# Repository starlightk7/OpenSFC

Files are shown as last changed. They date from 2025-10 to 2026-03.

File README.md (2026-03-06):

# OpenSFC

## Introduction

This repository contains OSHW Reproduction Parts related to the Super Famicom (SFC) / Super NES (SNES) game console under the umbrella name OpenSFC. While these parts are primarily developed from the Japanese Super Famicom models, you can build a North American SNES as well as long as you use the appropriate front and rear panels. See the documentation for details.

These parts are freely available under the terms of the [CERN-OHL-S](https://github.com/starlightk7/OpenSFC/blob/main/LICENSE) license for you to use, study, modify, or sell. The source files are provided as-is with no warranty or entitlement for support to you or any users that you sell manufactured boards to. See [LICENSE](https://github.com/starlightk7/OpenSFC/blob/main/LICENSE) and [NOTICE](https://github.com/starlightk7/OpenSFC/blob/main/NOTICE) for details. Please carefully read these files to understand your obligations if you choose to distribute this project or modifications of it.

## Sample Build

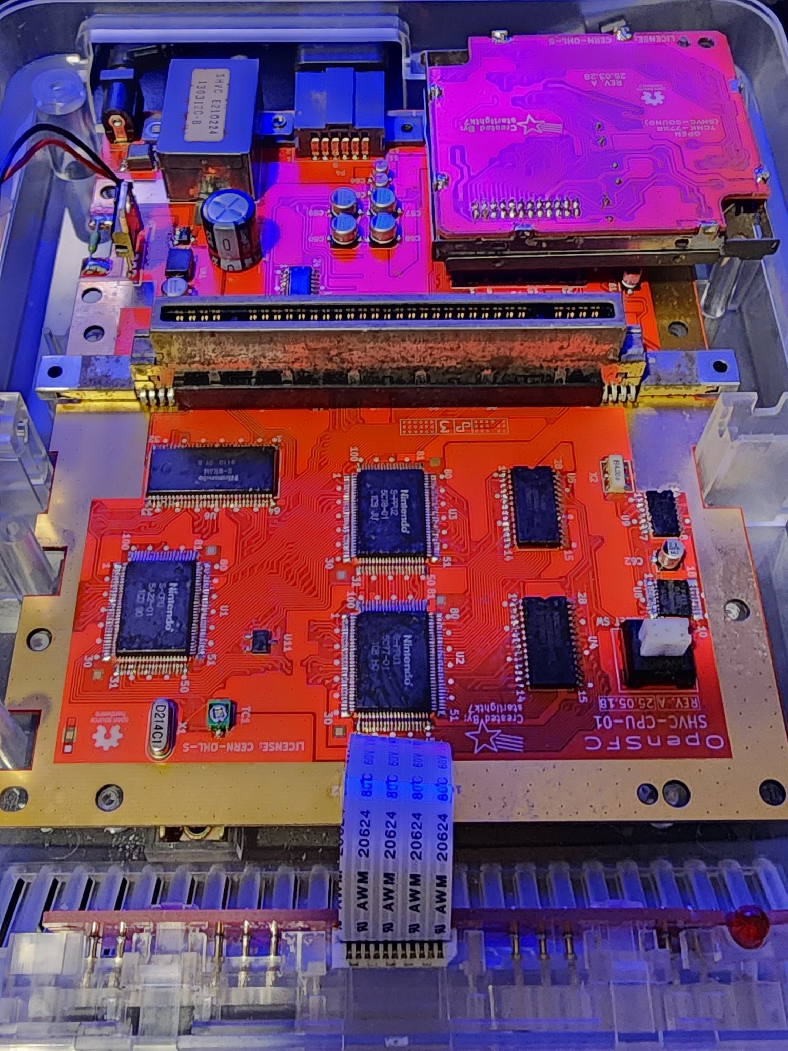
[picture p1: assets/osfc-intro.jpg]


## Usage

Suggested usage for the documents and boards in this repository:

* Studying the hardware and learning about it's function
* Aiding repairs and failure diagnostics through the created [schematics](https://starlightk7.github.io/OpenSFC/#/schematic) and boardviews
* Repairing broken consoles via replacement, reproduction boards and tested replacement [BOMs](https://starlightk7.github.io/OpenSFC/#/bom).
* Building a customized console as a DIY project, for hobby or educational purposes.

## Documentation

Please read the [documentation](https://starlightk7.github.io/OpenSFC/) carefully before using the project.

You can also watch SHVC install videos from [1upRestorations (English)](https://youtu.be/3N_iRRNhPbA), [Assistência Retrô (Portuguese)](https://www.youtube.com/watch?v=s9iTc--j23Y), or [Fenris Wolf Retro (English)](https://youtu.be/6wmiuE3He4w?si=xQSYrtJ7eRGYEiC7).

You can watch a controller install video from [1upRestorations (English)](https://www.youtube.com/watch?v=qigm2QdvjLU)

## Getting a Board

The project officially distributes boards from [Japan (inexpensive international shipping available)](https://ko-fi.com/starlightk7/shop), the [US](https://1uprestorations.com/collections/console-mod-parts/products/opensfc-bundle) and the [UK](https://www.retroupgrades.co.uk/product/opensfc-shvc-bundle). If you just wish to simply obtain a board for yourself, it will often be cheaper than ordering from the fab directly.

***Support is offered to those who purchased a board from a vendor listed below. No support is provided for fabricating these files on your own. If you choose that route, you should understand what you are doing and are responsible for ensuring it is done right. I am not responsible for any defects that may arise from improperly manufacturing these files, or for defects arising from modifications made by you or your PCB fab during manufacturing. If you produce these boards for sale without becoming an authorized distributor, you are responsible for any and all customer support related to the product as well as your compliance with the project's license***. 

If you have any questions about this, feel free to contact with questions. If you are interested in becoming an authorized distributor for your region, and thus gaining support for your users, please contact me via Discord or Twitter.

The ultimate goal of this project is to eventually document and reproduce all models, but it will take quite some time. In the meantime, I made the best overall parts (in my opinion) first. If you believe in the long term goal, consider subscribing on Ko-Fi; for the $1 tier you'll also gain access to weekly Dev Logs that teach how boards like these are made. Labor aside, donor boards to research, prototypes, and parts are all expensive, and those funds will help offset those costs to complete more boards.



Feel free to come chat with us on Discord: 

All boards in this project are 28-35 years old at the time of writing. All relevant patents worldwide have long expired. This project is not affiliated with or endorsed by the big N.

## Commissions

I do not have time to build commissions on a regular basis, however, there are members of the retro community whom offer this service.

| US/Canada | EU |
|---|----|
| [1upRestorations (United States)'](https://1uprestorations.com/collections/pre-modded-consoles/products/opensfc-custom-build) | [Modding Marius](https://moddingmarius.com/super-nintendo/)

## Disclaimer

**WARNING:** Doing a full build is an advanced project. Please carefully read the documentation and required skills and experience before purchasing or ordering a board. Purchasing boards and parts does not guarantee that you can be successful in doing a build. Significant experience in soldering and desoldering, along with a variety of tools are necessary. Your first build will likely not work on its first boot. Patience, analysis, and debugging will likely be necessary to bring the unit online. Order at your own risk. The author provides no guarantee of your success, and also cannot guarantee that any given vendor can fabricate these boards correctly. If you are ordering boards, please consult with your target vendor before ordering if you wish to order a board.

## Parts Index

### Motherboards

| Part Number | Description | Region | Status| Japan | United States | United Kingdom |
|---|---|---|---|---|---|---|
| SHVC-CPU-01 (1990) | The original 2-chip motherboard. This board is the best routed motherboard of all two chip models. Early 1/1/1 Units are extremely reliable. Late 2/1/3 units have a high failure rate. | NTSC-U / NTSC-J | Released | [Ko-Fi (Direct)](https://ko-fi.com/starlightk7/shop), [eBay (Direct)](https://www.ebay.com/itm/136746135648), [Etsy (Direct)](https://starlightretro.etsy.com) | [1upRestorations](https://1uprestorations.com/collections/console-mod-parts/products/opensfc-bundle) | [RetroUpgrades](https://www.retroupgrades.co.uk/product/opensfc-shvc-bundle) |
| SNS-CPU-GPM-01 (1991) | Contains the often failing CPU 2A. | NTSC-U / NTSC-J | In Progress | N/A | N/A | N/A |

### Sound Module

| Part Number | Description | Region | Status| Japan | United States | United Kingdom |
|---|---|---|---|---|---|---|
| TCMK-77XR SHVC-SOUND | The early type, missing resistors on the 2904. Repro for historical purposes only. | NTSC-U / NTSC-J | Planned | N/A | N/A | N/A |
| TCMK-77XR SHVC-SOUND F | This is the late model sound module which fixed missing resistors on the 2904. | NTSC-U / NTSC-J | Released | [Ko-Fi (Direct)](https://ko-fi.com/starlightk7/shop), [eBay (Direct)](https://www.ebay.com/itm/136746135648), [Etsy (Direct)](https://starlightretro.etsy.com) | [1upRestorations](https://1uprestorations.com/collections/console-mod-parts/products/opensfc-bundle) | [RetroUpgrades](https://www.retroupgrades.co.uk/product/opensfc-shvc-bundle) |

### Front Panel Board

| Part Number | Description | Region | Status| Japan | United States | United Kingdom |
|---|---|---|---|---|---|---|
| TCMK-81X CCK-N10 | Found in SHVC and GPM Super Famicoms | NTSC-J | Released | [Ko-Fi (Direct)](https://ko-fi.com/starlightk7/shop), [eBay (Direct)](https://www.ebay.com/itm/136746135648), [Etsy (Direct)](https://starlightretro.etsy.com)| [1upRestorations](https://1uprestorations.com/collections/console-mod-parts/products/opensfc-bundle) | [RetroUpgrades](https://www.retroupgrades.co.uk/product/opensfc-shvc-bundle) |
| TCMK-81X CCK-N20 | Found in SHVC and GPM North American SNESes | NTSC-U | Released | [Ko-Fi (Direct)](https://ko-fi.com/starlightk7/shop), [eBay(Direct)](https://www.ebay.com/itm/136746135648), [Etsy (Direct)](https://starlightretro.etsy.com) | [1upRestorations](https://1uprestorations.com/collections/console-mod-parts/products/opensfc-bundle) | [RetroUpgrades](https://www.retroupgrades.co.uk/product/opensfc-shvc-bundle) |

### Controllers

| Part Number | Description | Region | Status| Japan | United States | United Kingdom |
|---|---|---|---|---|---|---|
| 56V313A (1990.6) | Found in 1/1/1 SHVC controllers. 2x shift register model | NTSC-J / NTSC-U | Released | [Ko-Fi (Direct)](https://ko-fi.com/starlightk7/shop), [eBay(Direct)](https://www.ebay.com/itm/137100897247) | [1upRestorations](https://1uprestorations.com/products/opensfc-controllers) | [RetroUpgrades](https://www.retroupgrades.co.uk/) (Coming Soon) |
| 56V313B (1991) | Found in 2/1/3 SHVC controllers. 1x Obsolete Shift Register, no PAL support | NTSC-J / NTSC-U | Planned | N/A | N/A | N/A |
| 56V313D (1992+)  | Found in controllers for GPM and beyond. 1x Obsolete Shift Register | Universal | Released | [Ko-Fi (Direct)](https://ko-fi.com/starlightk7/shop), [eBay(Direct)](https://www.ebay.com/itm/137100898087) | [1upRestorations](https://1uprestorations.com/products/opensfc-controllers) | [RetroUpgrades](https://www.retroupgrades.co.uk/) (Coming Soon) |
| 56V313A | L/R Trigger Board | Universal | Released | [Ko-Fi (Direct)](https://ko-fi.com/starlightk7/shop) | [1upRestorations](https://1uprestorations.com/products/opensfc-controllers) | [RetroUpgrades](https://www.retroupgrades.co.uk/) (Coming Soon) |

### Cartridges

There are none currently in progress, but they are planned for future.

### Accessories

There are none currently in progress, but they planned for future.

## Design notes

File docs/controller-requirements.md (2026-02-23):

# Requirements

## Skills

The following skills are required to successfully complete this project

* Soldering Skills
  * Must be able to solder through hole resistors
  * Must be able to solder a SOIC/SOP style IC

* Desoldering skills
  * Must be able to desolder a SOIC/SOP style IC

* Multimeter
  * Must understand basic use of a multimeter and how to test continuity and voltage

## Tools

The following tools are required to successfully complete this project

* Minimum
  * Soldering iron
  * Solder
    * Leaded 63/37
    * Low Melt Solder (strongly recommended)
  * Flux
  * Desoldering wick
  * 3-11 220ohm 1/4w size through hole resistors.
  * 5mm hole punch
  * 0.1mm thickness sticker paper
  * 99% Isopropyl Alcohol
  * Q-Tips/Toothbrush for Cleaning
  * Multi-meter

* Recommended
  * Temperature controlled soldering iron
    * J-Tip for QFP Soldering / Desoldering
    * Spatula Tip (optional, but makes pre-tinning much easier)
  * Solder
    * Kester 63/37 w/ Rosin Core (any reputable brand is fine)
    * ChipQuik Low Melt Solder
  * Goot Wick Desoldering Braid
    * This stuff is the best braid I've ever used. Great for cleaning the chip legs.
  * Tacky Flux such as ChipQuik SMD291 (any brand is fine)
  * Kapton Tape
    * Protect the button contacts. The board is ruined if you get solder on them.
  * Anti-static wristband
    * Failure to use one may cause ESD damage to parts. This is not always instant; a zap may cause damage that may make it fail at a delay.
  * Safety glasses
    * Please wear them. The time you don't have them can be the time you really needed them
  * Fume extractor
    * Prolonged fumes are bad for you health. If you do not have an extractor at least work near and open window and blow a fan toward it if you can.

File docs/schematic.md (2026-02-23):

# Schematics

## Notes on Schematics
This page contains PDFs of schematics I created for OpenSFC.

Please note that my schematics are not traditional engineering schematics. I am not an engineer, just a hobbyist. I have seen many other hobbyists struggle to decode complex schematics and map them back to their boards, often needing someone else to interpret for them. 

I envision the primary users of my boards being hobbyists with a little knowledge of a soldering iron who want to repair their unit or build a fun project, not professional engineers. As such I have chosen to draw my schematics more as "Schematic Art". They are laid out like a visual depiction of the actual board. 

This will likely feel messy and inefficient to a professional engineer, but for an average person they will clearly be able to correlate what they are looking at to the board they are working on and see the color coded flow of data by function when debugging. 

This approach will have people who both like and dislike it and that's okay. The beauty of Open Source is anyone is free to remix it to suit their needs. If you prefer a more traditional schematic, you can also reference the existing  [J. Donaldson schematic](https://wiki.superfamicom.org/uploads/snes_schematic_color.pdf). Please note that despite having a section for the SHVC-SOUND Pinout the Donaldson Schematic is a GPM Schematic. There are numerous differences with SHVC and other models, so you cannot count on it for passive values when doing an OpenSFC SHVC build. You can, however, see how ICs are generally connected with it.

## PDF Diagrams

* Motherboard
  * [SHVC-CPU-01 Front](https://starlightk7.github.io/OpenSFC/assets/SHVC-CPU-01-Front.pdf)
  * [SHVC-CPU-01 Back](https://starlightk7.github.io/OpenSFC/assets/SHVC-CPU-01-Back.pdf)
* Sound Module
  * [TCMK-77XR SHVC-SOUND F](https://starlightk7.github.io/OpenSFC/assets/TCMK-77XR-F.pdf)
* Front Panel Controller Board
  * [TCMK-81X CCK-N10 SFC Style (SHVC/GPM)](https://starlightk7.github.io/OpenSFC/assets/TCMK-81X_CCK-N10.pdf)
  * [TCMK-81X CCK-N20 SNES Style (SHVC/GPM)](https://starlightk7.github.io/OpenSFC/assets/TCMK-81X_CCK-N20.pdf)
* Controllers
  * [56V313A (1990 Model)](https://starlightk7.github.io/OpenSFC/assets/53V313A.pdf)
  * [56V313D (1992+ Model)](https://starlightk7.github.io/OpenSFC/assets/53V313D.pdf)
  * [56V314A (Shoulder Button)](https://starlightk7.github.io/OpenSFC/assets/53V314A.pdf)

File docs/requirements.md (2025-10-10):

# Requirements

## Skills

The following skills are required to successfully complete this project

* Soldering Skills
  * Must be able to solder through hole components
  * Must be able to solder 0805 size SMD passives
  * Must be able to solder fine pitch QFP chips

* Desoldering skills
  * Must be able to desolder through hole components
  * Must be able to desolder QFP chips without damaging them

* Multimeter
  * Must understand basic use of a multimeter and how to test continuity and voltage

## Tools

The following tools are required to successfully complete this project

* Minimum
  * Soldering iron
  * Solder
    * Leaded 63/37
    * Low Melt Solder (strongly recommended)
  * Flux
  * Desoldering wick
  * Desoldering Gun or Pump (Strongly Recommneded)
  * 99% Isopropyl Alcohol
  * Q-Tips/Toothbrush for Cleaning
  * Multi-meter

* Recommended
  * SNES Burn In Cart, or ROM on a Flash Cart
    * Access to this highly recommended. If you don't know if the chips in your system work properly to begin with you will have a hard time debugging if it is your first build.
    * If using SD2SNES, turn off all in-game hooks and save states or it can cause errors on the tests, particularly with the timing tests.
  * Temperature controlled soldering iron
    * J-Tip for QFP Soldering / Desoldering
    * Spatula Tip (optional, but makes pre-tinning much easier)
  * Solder
    * Kester 63/37 w/ Rosin Core (any reputable brand is fine)
    * ChipQuik Low Melt Solder
  * Goot Wick Desoldering Braid
    * This stuff is the best braid I've ever used. Great for cleaning the chip legs.
  * Tacky Flux such as ChipQuik SMD291 (any brand is fine)
  * FR-301 Desoldering Gun or Equivalent
    * 1.6mm Tip for Controller Ports
    * 0.8mm Tip for Connectors
  * Kapton Tape
    * Protect the beautiful ENIG plane
  * Anti-static wristband
    * Failure to use one may cause ESD damage to parts. This is not always instant; a zap may cause damage that may make it fail at a delay.
  * Safety glasses
    * Please wear them. The time you don't have them can be the time you really needed them
  * Fume extractor
    * Prolonged fumes are bad for you health. If you do not have an extractor at least work near and open window and blow a fan toward it if you can.

* Optional
  * Some people may want Hot Air Station or Hot Plate, but these are not strictly necessary. If you don't have one you do need a J-Tip and ChipQuik Low melt. I recommend low melt solder regardless and keeping your station temperature lower to avoid damaging the chips.

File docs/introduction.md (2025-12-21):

# Introduction

Welcome to OpenSFC!

This is an Open Source Hardware (OSHW) project aimed at creating 1:1 reproduction part for SFC / SNES consoles for use in repair and customization. In addition, parts will be documented, schematics drawn, and replacements for obsolete parts identified where possible.

# Sample OpenSFC Build
image|300x400

# Install Videos

These videos from the community demonstrate the installation process:
* [1up Restorations OpenSFC Installation Video (English)](https://youtu.be/3N_iRRNhPbA)
* [Assistência Retrô OpenSFC Install Video (Portuguese)](https://www.youtube.com/watch?v=s9iTc--j23Y)
* [Fenris Wolf Retro OpenSFC Installation Video (English)](https://youtu.be/6wmiuE3He4w?si=xQSYrtJ7eRGYEiC7)

# Why Would I Want This?

There are many reasons why you might want an OpenSFC part

* Repairing Damage to Original Boards
  * Boards can be damaged by a variety of incidents
    * Leaked Capacitors
    * Liquid Spills
    * Flooded basements/warehouses
    * Humidty damage from improper storage
    * Failed mod attempts
  * These parts can serve as replacement parts to repair the unit.
* Learning
  * You may want to learn about how our beloved console works
  * The ability to build one by hand is an excellent way to gain some insight into how the console works
* Customization
  * Some people find joy in customizing a beat-up unit while restoring it, and OSHW parts are great for that. 
  * Please be responsible and choose a rustic unit for your restoration so that we don't needlessly deplete the supply of original units in good condition
* Integrating fixes/mods
  * The reference board is a 1:1 reproduction, but you may want to customize it.
  * You may want to remix a custom board that integrates mods or fixes of your choice into the board.
  * Anyone can create a derivative under the terms of the [CERN-OHL-S](https://ohwr.org/cern_ohl_s_v2.txt) license.

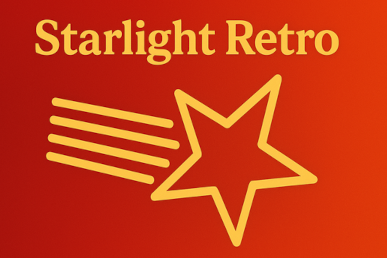
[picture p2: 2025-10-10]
assets/header.png

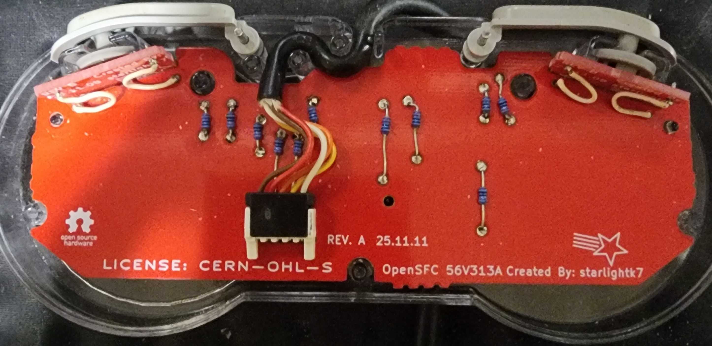
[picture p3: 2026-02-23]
assets/56V313A_Back.jpg

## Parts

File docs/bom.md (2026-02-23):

# Bill of Materials (BOM)

## Parts List

A list of compatible parts are 
The [following spreadsheet](https://docs.google.com/spreadsheets/d/1zoEOy6N3Ll8hXqOk3DKFTWjwM4TRxby1sjQ6yHRMT5c) contains a description of required donor parts for the project as well as a mouser-based BOM if you'd like to use as many new parts as possible'. Each board has its own sheet.

Quick Links:

## Interactive Guides for Assembly Assistance

These files visually show you where a given part number is located on the board. It is harder to keep these resources up to date with in-stock parts, so the actual part list is maintained in the spreadsheet above.

* [SHVC-CPU-01](https://starlightk7.github.io/OpenSFC/ibom/ibom-shvc.html)
* [SHVC-SOUND F](https://starlightk7.github.io/OpenSFC/ibom/ibom-sound.html)
* [SFC Front Panel](https://starlightk7.github.io/OpenSFC/ibom/ibom-n10.html)
* [SNES Front Panel](https://starlightk7.github.io/OpenSFC/ibom/ibom-n20.html)

## Donor Identification

### Japanese Units

These are general guidelines for identifying Japanese units. Note that there may be exceptions if someone has shell swapped units.
 * SHVC
   * 4 Rubber Feet on Bottom. This is your primary target.
 * GPM
   * 2 Rubber Feet, 2 Plastic on Bottom.
   * Serial Begins with S0/S1/S2 (no "SM")
 * RGB/APU/1-CHIP
   * 2 Rubber Feet, 2 Plastic on Bottom.
   * Serial Begins "SM"

### Compatibility Notes

#### SHVC-CPU-01 Repro
As of the time of writing, the only out of box fully compatible unit with the current SHVC-CPU-01 repro is the SHVC, because of the need for the proprietary SHVC-SOUND connectors. You can harvest chips from any broken unit though. It does not matter which revision of the chips you use. Do note though that CPU 2A is substantially more likely to fail under normal circumstances than CPU 1 or 2B. CPU 2A is found in late SHVCs and early GPMs.

A GPM unit can be converted if 2.0mm pitch pin headers of the right length are used for the SHVC-SOUND, and new op-amps are used. I am working on identifying a set that will allow it to sit cleanly on the screwpost. No support is provided for this currently until a fully compatible set of parts is identified.

Converting a RGB unit would additionally require the older BA6592F / S-ENC encoder if is RGB-01, and also the older NEC µPD6376 if RGB-02. These parts are obsolete, though can sometimes be found on AliExpress. The supply is spotty though and some sellers are scammers. Not recommended at this time until reliable part sources are identified.

Converting an APU unit is not courrently possible. A custom SHVC-SOUND that is compatible with the S-APU unit would be needed. I plan on making one in the future.

If you wish to build a North American SNES, please note that neither aftermarket shell option includes the necessary springs for the North American Shell. So you cannot have a properly functioning case with a Japanese donor. I am currently working on identifying suitable replacement springs to solve this.

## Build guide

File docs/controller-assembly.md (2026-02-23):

# Assembly

## Official Install Video

Coming Soon

## General Guidelines

**Please carefully follow the following steps**

Identify which controller model your donor is before purchasing. You will need the matching board as your donor.

WARNING: if you are sloppy with your work consider covering the button contacts with kapton tape. If you get any solder on the button contacts the board is permanently damaged and when it oxidizes the pads will stop working correctly. As such, if you happen to be producing your own boards, DO NOT USE HASL BOARDS for controllers. They will degrade quickly especially in humid climates.

### 1990 Model:

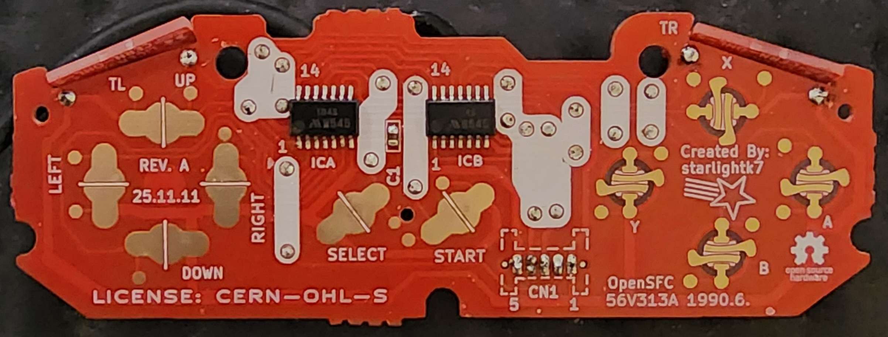
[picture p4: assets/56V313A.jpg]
image|601x228


* Features 2 8-bit shift registers with a non-standard pinout
* Various carbon printed resistors are used (white silk on the ENIG repro)
* Desolder and transfer the 2 shift registers. Chipquik will make it super easy.
* Transfer the decoupling capacitor C1
* Install 220ohm 1/4W size through hole resistors to replace the carbon, as ENIG has no resistance
* For this model, I recommend installing them on the back like so to avoid conflicts with pegs. Be conscious of clearance.
* Install the resistors *before* the cable connector to make your life easier on the ones near it

image|601x292

### 1992 Model:

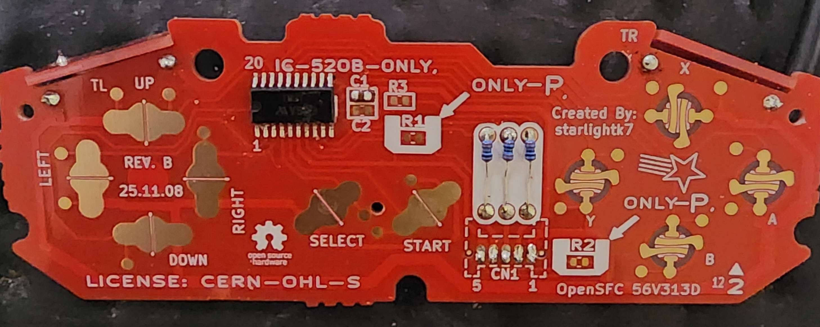
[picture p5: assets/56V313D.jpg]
image|601x239


* Features a single 16-bit shift registers with a non-standard pinout
* 3 carbon printed resistors are used as part of input protection
* Desolder and transfer the shift registers. Chipquik will make it super easy.
* Transfer the decoupling capacitor C1. 
* If PAL donor board, transfer the Only-P resistors
* Install 220ohm 1/4W size through hole resistors to replace the carbon, as ENIG has no resistance
* For this model, I recommend installing them on the front like so to avoid conflicts with pegs. Be conscious of clearance, they must be pulled up top to not hit.
* You may also install these on the back like the 1990 model, but in that case due it before installing the cable connector.

### Tuning Sensitivity

Making custom controllers is a bit of an art due to micro-tolerance issues. All parts being produced today tend to have ~0.1~0.3mm tolerance ranges; this applies to everything, PCBs, Silicone Pads, Dpads/Buttons, Shells, etc.

When building a custom controller it is possible that the combination of parts you use will have microtolerance issues, leading to decreased sensitivity on inputs. This also effects the stock PCB, which is why 3rd party Silicone pads are notorious for stiff diagonals. As my boards are 1:1 copies of stock, they may encounter the same problems.

Luckily, there is a cheap and easy way to tune these issues to your liking.

Before tuning, turn on and test your controller. I recommend doing something like sliding in Super Mario and also diagonal movements in Zelda. It is highly possible, especially with 3rd party silicone pads or cases. Basically, 3rd party pads often are actually slightly big or small compared to the original ones. When you press, that makes them bend differently. I took some mitigations against this by widening the stock contacts a little and minimizing the distance between size, but it occasionally happens on a diagonal.

I recommend taking a 5mm hole punch onto 0.1mm sticker paper. Then start to augment the d-pad like so:

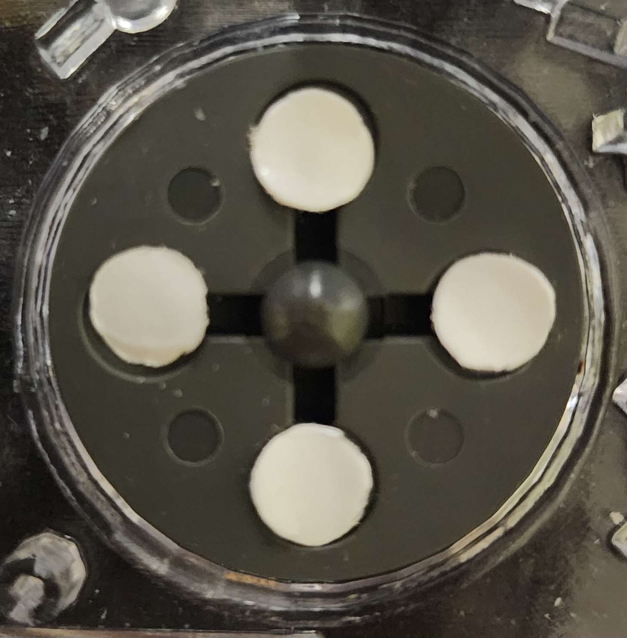
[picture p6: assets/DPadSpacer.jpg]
image|364x370


Do it in 0.1mm increments until it feels right to you. Basically what happens here is, each layer of sticker will reduce how hard you must press on the pad to make contact. Usually no more than 0.3mm is needed

If you are using 3D printed parts, tuning is often not necessary since they are naturally thicker. But if you have any difficulty, use this process.

If you want to tune the buttons, put the sticker on the underside of the buttons.

If you want to tune the L/R triggers, you can do the underside of the trigger or the underside of the trigger board.

One tuned, the controller should feel very comfortable. Feel free to reach out if you need help

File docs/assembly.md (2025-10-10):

# Assembly

## Official Install Video

[1upRestorations](https://1uprestorations.com) has graciously provided an [official install video](https://youtu.be/3N_iRRNhPbA).

## General Guidelines

**Please carefully follow the following steps**

* Discharge the donor unit with power on while unplugged before starting. There is no bleeder on the filter cap, so it retains charge and can cause damage to the sytem or blow the fuse if you do not discharge it before working on the unit.

* Build the sound and controller modules first and test them independently. 
  * If your donor is working, you can test your sound module in it before removing the chips from the motherboard. 
  * The system will not boot if the audio module doesnt work, so being able to verify that piece independently is very nice. 
  * Hakko FR-301 with 1.6mm tip makes quick work of swapping the controller input board.

* Before doing anything on the mainboard, I recommend protecting the ENIG ground plane on the new board with kapton tape. 
  * **WARNING: If you contaminate the ENIG gold with solder it is PERMANENT DAMAGE. There is no getting it out without the ENIG being replated and the solder will ruin the beautiful gold look** 
  * Additionally, there are many small enig test pads all over the back of the board. 
     * You will need to decide how OCD you will be about contamination. 
     * When I assembled my first board by hand I moved a small piece of kapton around as I went to protect these. As such, my board retained a very pretty gold emphasis.
     * You must control paste very well to not contaminate the pads if you are using an oven/hotplate/hotair assembly. If you want it to be perfect I recommend hand soldering with kapton shields.

* There are several options for assembly
  * You can solder each part by hand. 
  * You can pre-tin the pads and transfer with hot tweezers if you have them. 
    * Transplants can also be done extremely fast that way.
  * You can dispense solder paste, place the parts, and bake them in a reflow oven or on a hot-plate
  * Clean the board good with IPA before testing. Some types of flux are conductive and can cause shorts.
    * If you have an ultrasonic cleaner, I recommend using it, but do so *before* installing the Crystal Oscillators / Ceramic Resonators as they can be sensitive to ultrasonic cleaning.
    * If you do not have one, a great budget strategy is to take a gallon freezer bag, pour IPA into it, and put the board inside. You can gently shake it, as well as reach in a tooth brush and scrub with more volume, and without the IPA evaporating quickly.
* I recommend doing the back side first or the board wont sit level while youre doing it and that sucks

* Before soldering any chips **pre-tin all of the pads or you'll have a difficult time especially if you are a novice**. 
  * The easiest way is if you have a spatula tip, as that can quickly pre-tin them evenly with little risk of burning a pad. I do it around 300c with a little flux.
  * If you do not have a spatula tip, wick away excess solder so that when you place the chip it lays flat, otherwise you'll have trouble with alignment

* After soldering chips, poke test each leg with tweezers for any loose. 
  * Looks can be highly deceiving and so can the multimeter as the pressure from the tip will often provide enough pressure to conduct even if its loose.
  * The most common cause of issues is a loose QFP leg or cold joint on one.

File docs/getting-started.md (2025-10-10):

# Getting Started

Welcome! This is a placeholder page you can edit or replace.

- Navigation lives in `/docs` and is configured in `DOC_PAGES` in `script.js`.
- Images placed under `/assets` can be referenced as `../assets/...`.

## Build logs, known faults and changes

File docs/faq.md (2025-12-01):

# FAQ

**Q:** Will you be doing boards for other models?

**A:** I intend to eventually reproduce all NTSC variants, however this will take quite some time. I can make no guarantees on the timing of release. In the meantime, the best routed 2-CHIP SFC board is the SHVC which is already reproduced. These have the least amount of quality problems. For PAL consoles, please google the nonSNES project. I am currently in need of SNS-1CHIP-01 and SNS-1CHIP-03. I also need a US variant of an RGB/APU/1-CHIP in order to look at the late model controller input board. If you wish to sell or donate one of these units for R&D, please contact me.

**Q:** Can I build a SNES instead of an SFC?

**A:** Yes, as long as you buy the correct front panel and get a SNES rear power panel, either from a donor or one of the aftermarket parts. However, if your donor is a Super Famicom, none of the aftermarket kits current include the springs required for the shell, and the ones from the Super Famicom are NOT compatible. I working on identifying aftermarket replacements, but in the meantime, if you want to build a SNES, your donor should also be one to use these springs.

**Q:** Why is red significantly more expensive?

**A:** The fabs charge a substantial premium for red, and this premium is amplified x3 because of there being 3 boards. Unfortunately even with a volume purchase there's no way to avoid the price needing to be higher 😔

**Q:** Can I commission you for a pre-built?

**A:** In general I will not have time to do this on an ongoing basis, however, I may irregularly list pre-builts on the Ko-Fi store of units that were used for build validation. Once these are gone, they're generally gone unless there is development need to build another. [1upRestorations](https://1uprestorations.com) will provide a [custom build service](https://1uprestorations.com/collections/pre-modded-consoles/products/opensfc-custom-build) for customers in the US/Canada if you wish to commission a pre-built. [Modding Marius](https://moddingmarius.com/super-nintendo/) will take commissions for a pre-built out of France for EU residents.

**Q:** Can I use **&lt;insert mod x&gt;**?

**A:** Any mod that is compatible with the original SHVC should be compatible with OpenSFC. However, if you have modified the BOM, or done other community recommended fixes, keep in mind that deviation from the stock part configuration may adversely effect mods, especially in the case of edge mods.

**Q:** Why didn't you integrate **&lt;insert common community bodge fix&gt;**?

**A:** I am first and foremost most interested in historical preservation, which means preserving the stock design. While I am open to making revised versions in the future, not all of these fixes and mods are compatible with each other. I want to study the issues in detail before investing in any enhanced boards. I cannot promise I will make any such boards in the future, but there is nothing stopping someone else from doing so either. You may also freely apply these fixes yourself in the same way as stock, or remix the board to include them and order a copy for yourself.

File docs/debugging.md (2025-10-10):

# Debugging

This page will cover commons checks and procedures.

## The Basics

You will need to use a multimeter for diagnostics. There are two main types of tests you will need to perform: continuity and and voltage.

### Continuity Tests
* This will test that there is an electrical connection between the two points you touch with your probes.
   * Turn multimeter to continuity mode.
   * **Before testing, unplug the unit and turn the power button on to discharge the filter cap**. You will see the power LED briefly flicker. Never test continuity with the unit plugged in as you can damage components
   * Touch the probe between the two points. You should get 0 and a beep if successful. If you do not hear a beep, the number on the screen is the resistance between the points.

## Controller Module
* Before power on, ensure the filter cap is discharged and
  * Check for short between VCC/GND
    * Power off, filter cap discharged. Ribbon connected to the board.
    * Turn to Continuity Mode
    * Touch the red probe to the VCC pin on the connector. 
    * Touch the black probe to GND. Use the GND pin on the connector
    * You should not hear a beep and should see several hundred ohms of resistance. If you hear a beep DO NOT POWER ON. Fix short first.

## Sound Module

* Before power on.. 
  * Check for short between VCC/GND
    * Power off, filter cap discharged or SHVC SOUND disconnected from motherboard
    * Turn to Continuity Mode
    * Touch the red probe to the VCC pin on the connector. 
    * Touch the black probe to GND. The shield is connected to ground, or you can use the GND pin.
    * You should not hear a beep and should see several hundred ohms of resistance. If you hear a beep DO NOT POWER ON. Fix short first.
  * Check for short between AVCC/GND
    * Power off, filter cap discharged or SHVC SOUND disconnected from motherboard
    * Turn to Continuity Mode
    * Touch the red probe to the AVCC pin on the connector.
    * Touch the black probe to GND. The shield is connected to ground, or you can use the GND pin.
    * You should not hear a beep and should see several hundred ohms of resistance. If you hear a beep DO NOT POWER ON. Fix short first.
* If the unit doesnt work, proceed in this order:
  * Verify 5V power rail
    * Multimeter in DC Voltage mode.
    * Use the VCC pin on the connector. Look for stable 5V (voltage mode, power on).
    * The shield is connected to ground, or you can use the GND pin.
    * Look for stable 9V (DC voltage mode, power on).
  * Verify 9V power rail
    * Multimeter in DC Voltage mode.
    * Touch the red probe to the the AVCC pin on the connector.
    * Touch the black probe to GND. The shield is connected to ground, or you can use the GND pin on the connector.
    * Look for stable 9V (DC voltage mode, power on).
  * Verify clock
    * The ceramic resonator is the clock, but you will destabilize it if you measure it directly. Instead check for activity on Pin 16 (CLK, lower left) on the uPD6376. If it isn't dead, you've got clock.
  * Verify SMP/DSP pins
    * Poke test each of the legs with the unit is off. Make sure not on floating
    * Use a microscope, reading glasses or your cell phone camera to check for bridges.
  * At this point the unit should be booting if attached to a working motherboard.

* If boots but no audio
  * Verify soldering in the op-amp/encoder section of the board.

* If audio sounds too quiet/loud: 
  * Check for mistakes in capacitor values in the op-amp circuit

# Motherboard

## Initial Bring Up

* Before power on:
  * Check for shorts on 5V/GND
    * Unplug unit
    * Discharge filter cap
    * Red probe right leg of 7805
    * Black probe middle.
    * No beep expected.
  * Check for shorts between 9V/GND
    * Unplug unit
    * Discharge filter cap
    * Red probe left leg of 7805
    * Black probe middle.
    * No beep expected.

* If the unit doesnt work, proceed in this order:
  * Verify power rails
    * Power On
    * DC Voltage Mode
    * 5V
      * Red Probe: Right leg of 7805
      * Black Probe: Use the exposed GND rim to prevent accidental short from touching your probes.
    * 9V
      * Red Probe: Left leg of 7805
      * Black Probe: Use the exposed GND rim to prevent accidental short from touching your probes.
  * Verify clocks
    * Voltage probe for life on CIC CLK (see schmatic)
    * Voltage probe for life on SYSCLK (see schmatic)
  * Verify Sound module
    * See above section for tests
  * Verify CIC

**At this point should be booting in some form**

## Further Troubleshooting
* No Power:
  * Check fuse. Not resettable so if blown needs to be replaced. Do not use slow blow fuses. 
    * Unplug unit
    * Discharge filter cap
    * Continuity test across the fuse
    * Multimeter should beep
  * If installing a resettable fuse, make sure its fast blow at least as fast as the pico fuse or the hardware may be damaged. 
  * A slow blow fuse will likely damage things before tripping.

* Power Brownout (power is significantly less than 5v at the 7805 output)
  * Make sure you used the right diode arrays in the right spot. If they are swapped you will brown out.

* Black Screen
  * If you have CPU 2A, pray it wasn't dead if you didn't verify it before-hand with the SNES burn in test.
  * Verify CPU<->S-WRAM pins
    * Poke test all legs

* Scrambled graphics:
  * Verify PPU<->VRAM pins
    * Poke test all legs

* Bad Color:
  * Verify video output lines (RGB, etc) lines
    * Use the color codes lines on the schematic.
    * First inspect for soldeirng issues
    * Probe for life at each point.
    * In particular, check the transistors.

* No Input
  * Verify connector/ribbon orientations

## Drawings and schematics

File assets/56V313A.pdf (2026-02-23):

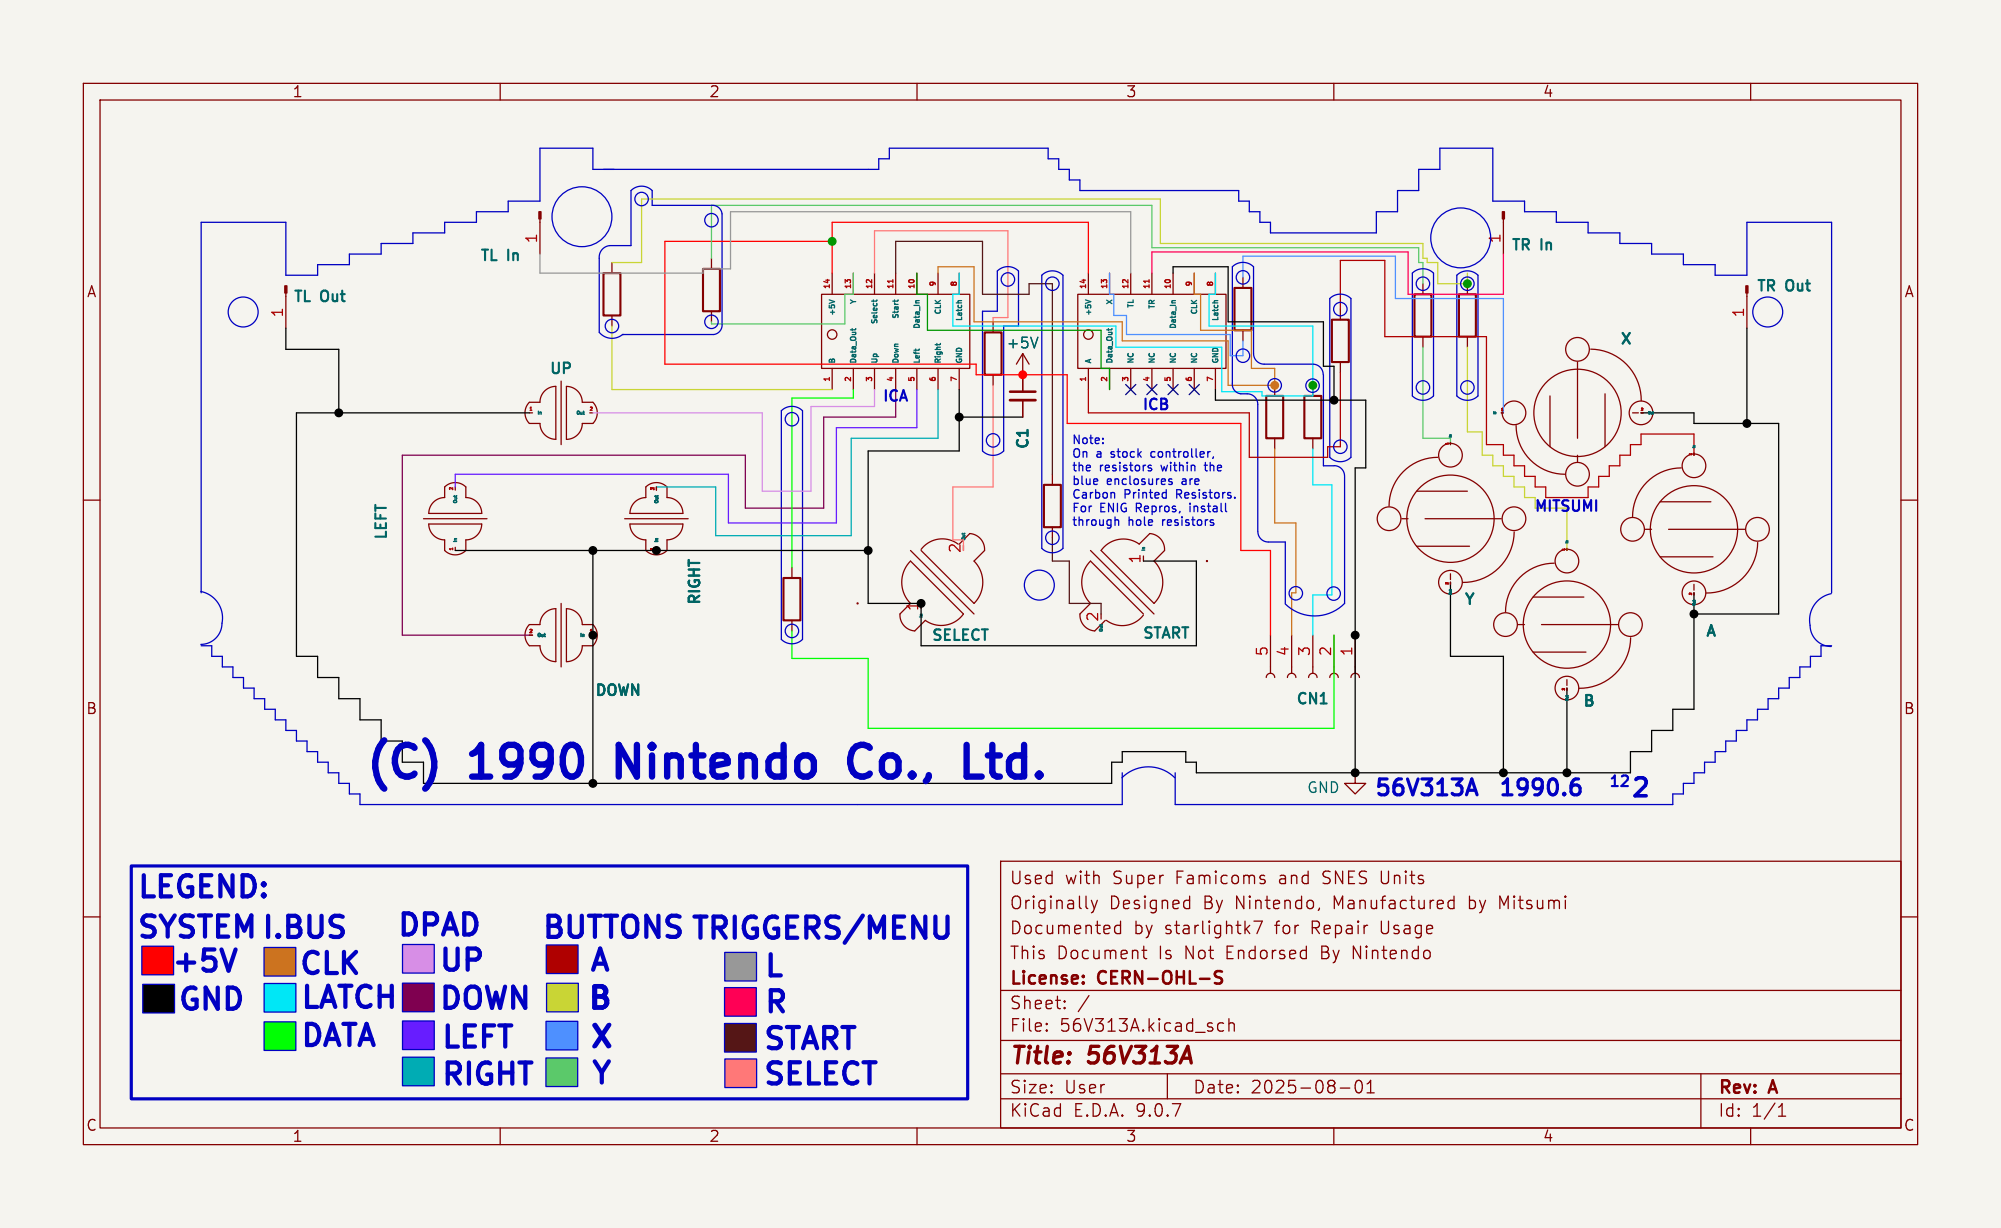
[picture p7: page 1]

Note: On a stock controller,

1 CN1 Out 2 In 1 SELECT In

File: 56V313A.kicad_sch Sheet: / License: CERN-OHL-S

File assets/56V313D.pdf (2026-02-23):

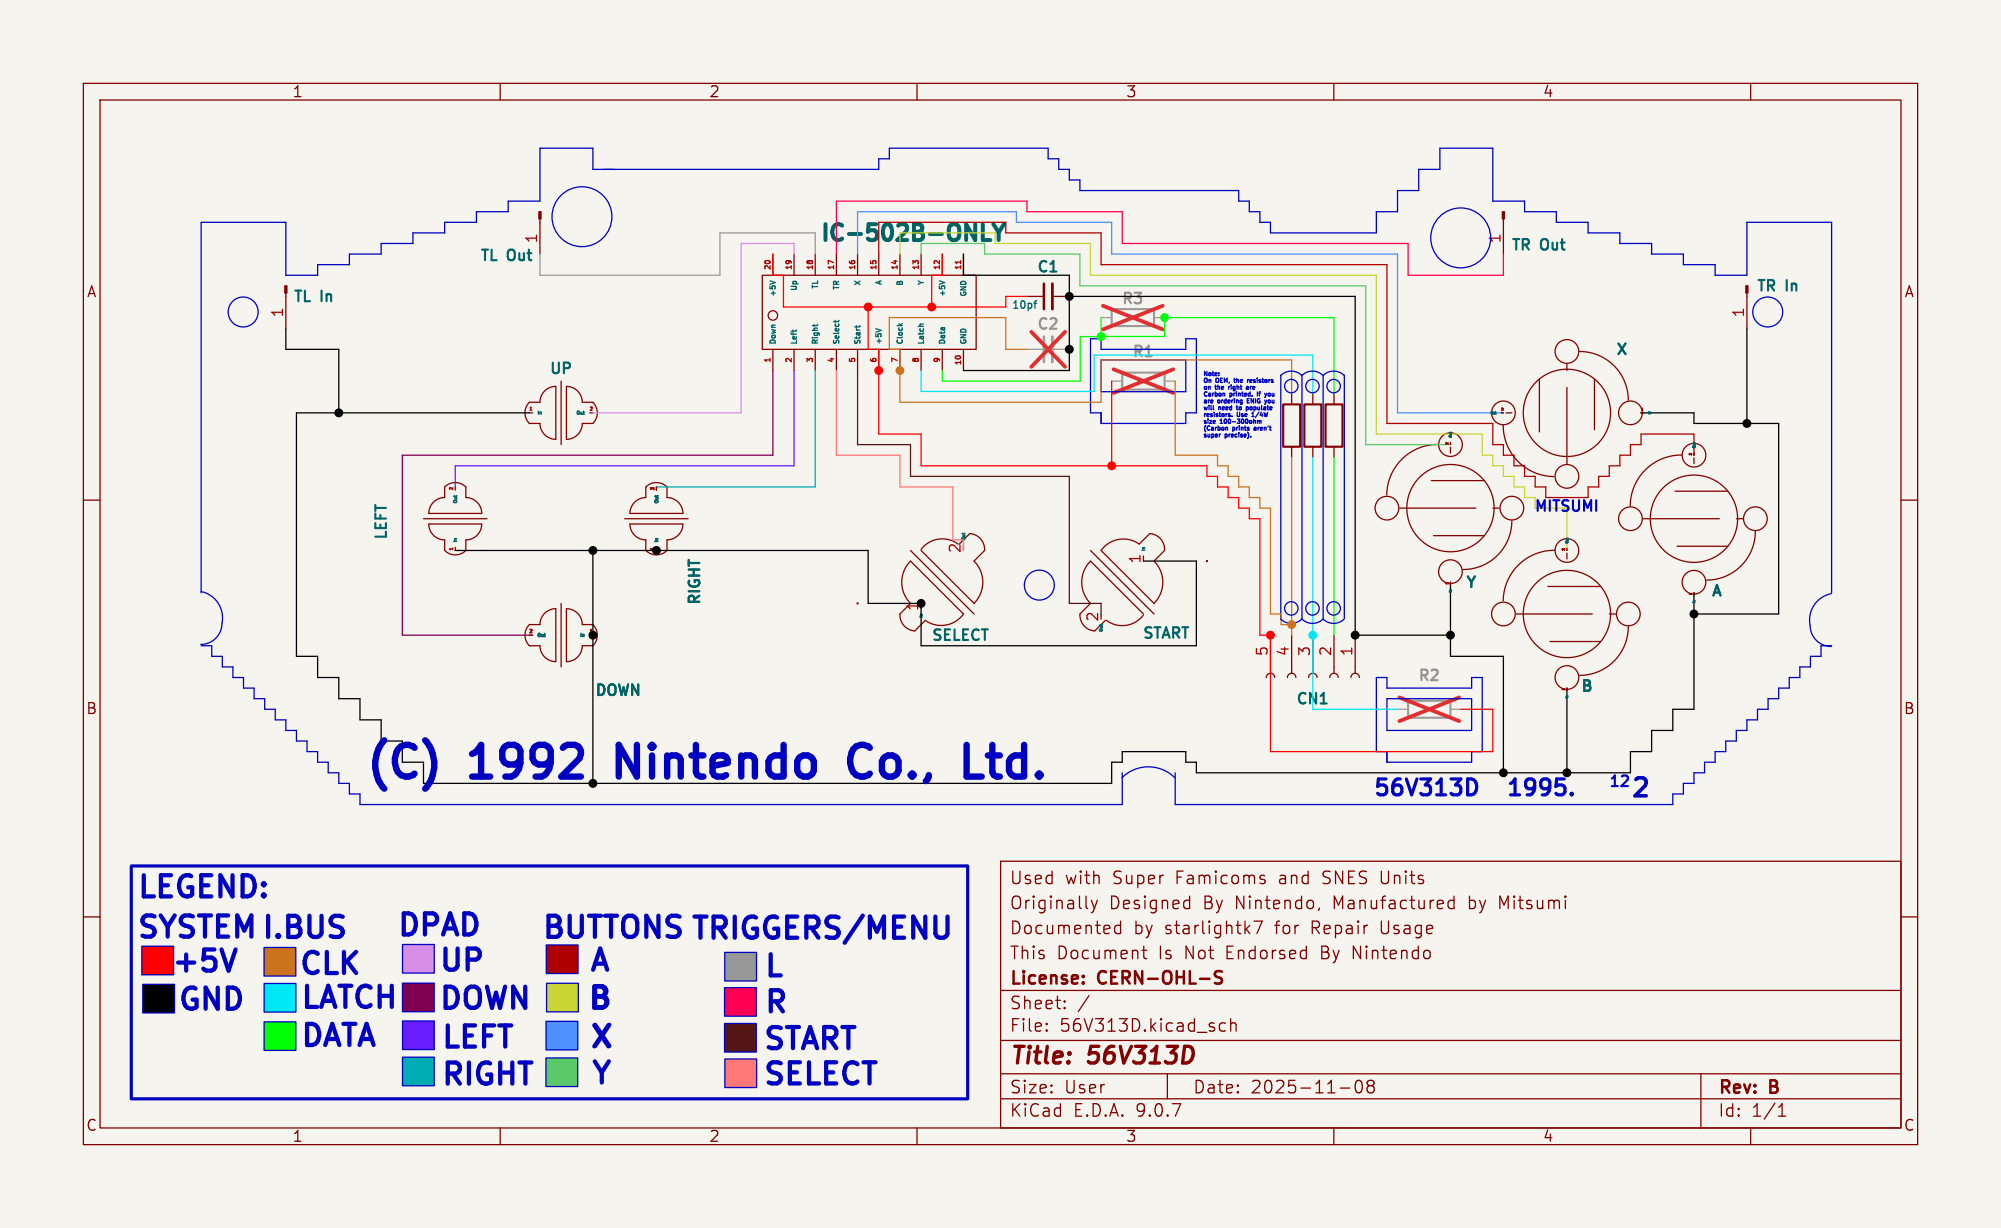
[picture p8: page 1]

9 GND 11 GND 10 IC-502B-ONLY

1 Up 19 Left 2 TL 18 Right 3 TR 17 Select 4 X 16 Start 5 A 15 +5V

1 Out 2 B Out 2 In 1 START

File: 56V313D.kicad_sch Sheet: / License: CERN-OHL-S

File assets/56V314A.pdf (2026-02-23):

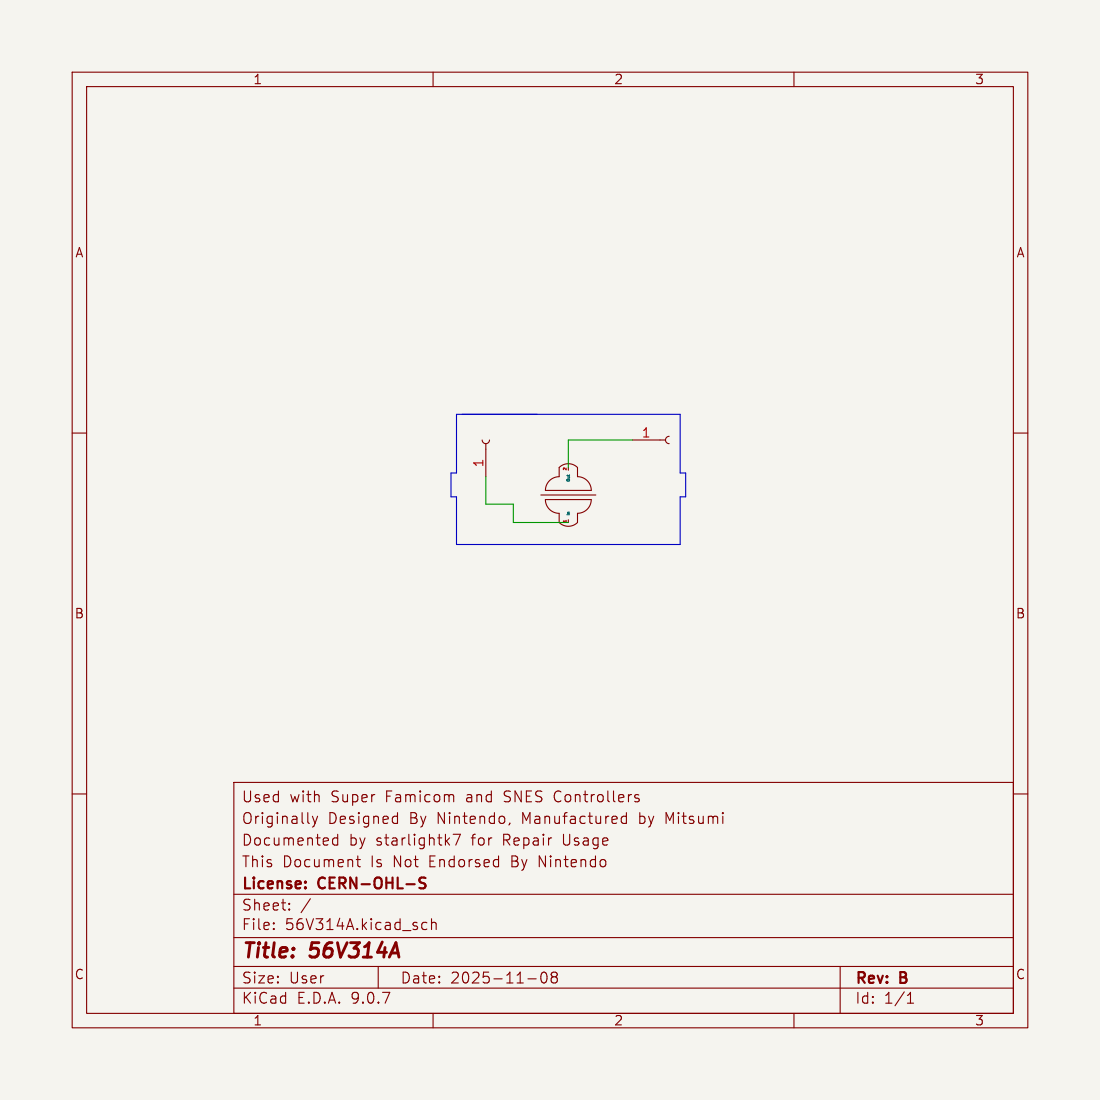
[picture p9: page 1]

File: 56V314A.kicad_sch Sheet: / License: CERN-OHL-S

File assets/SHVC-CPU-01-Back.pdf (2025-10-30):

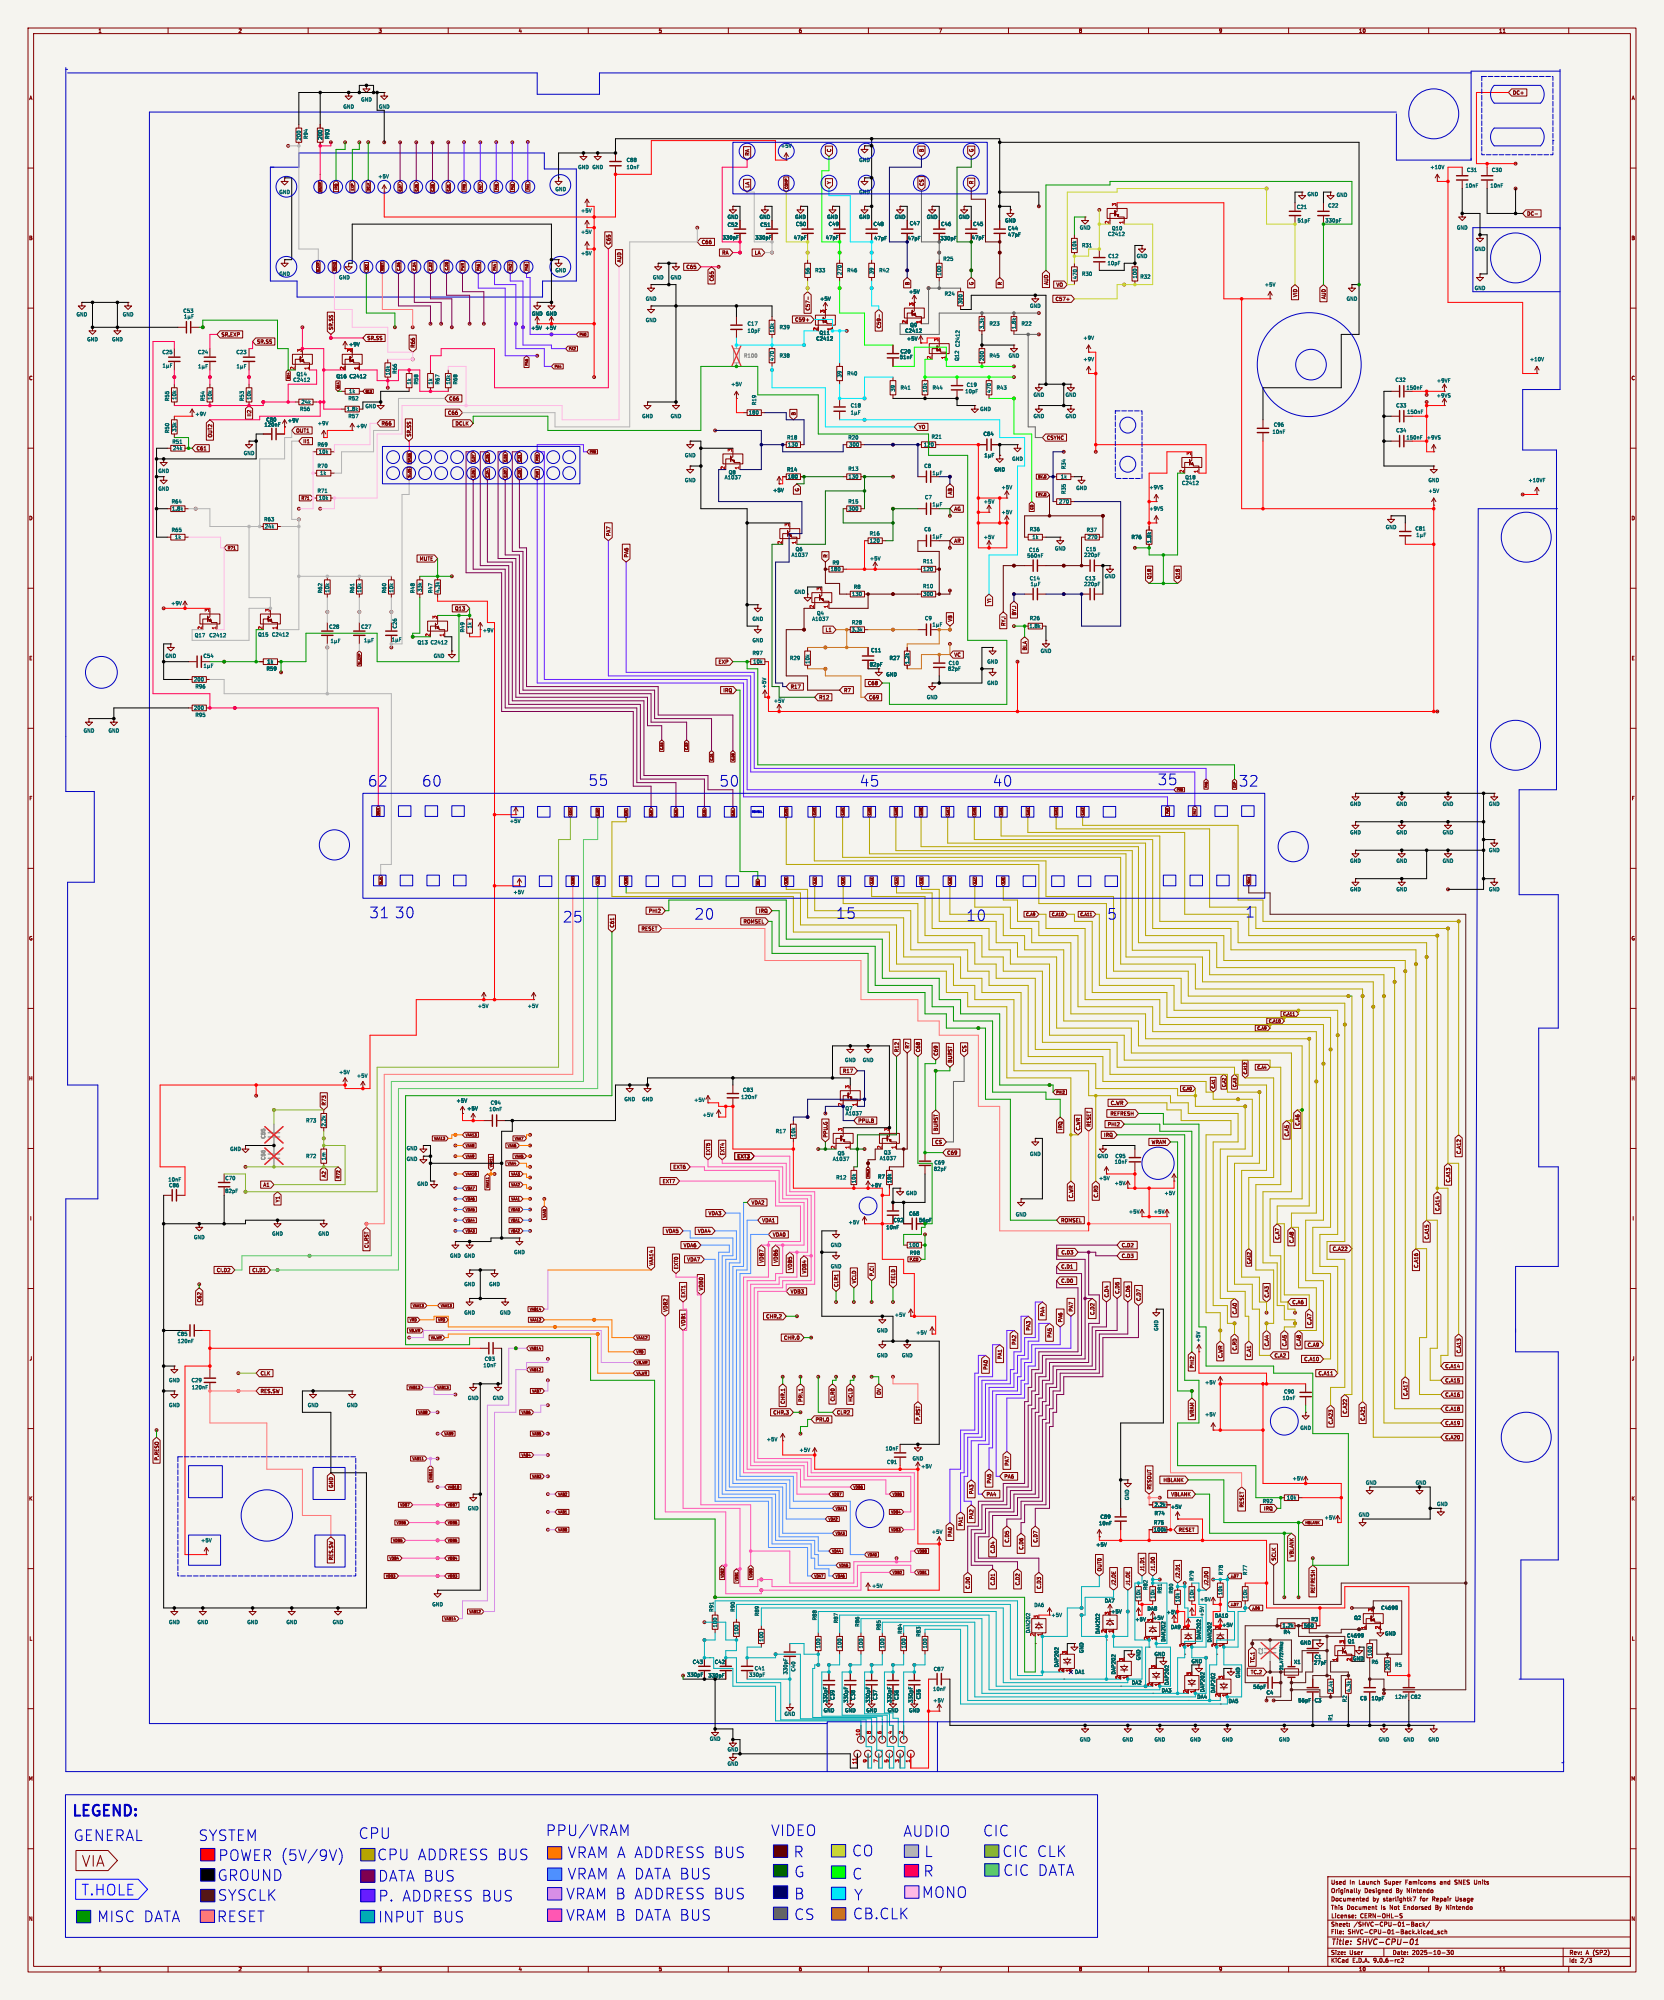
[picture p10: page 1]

G CI.RST SR.IN

File: SHVC-CPU-01-Back.kicad_sch Sheet: /SHVC-CPU-01-Back/ License: CERN-OHL-S

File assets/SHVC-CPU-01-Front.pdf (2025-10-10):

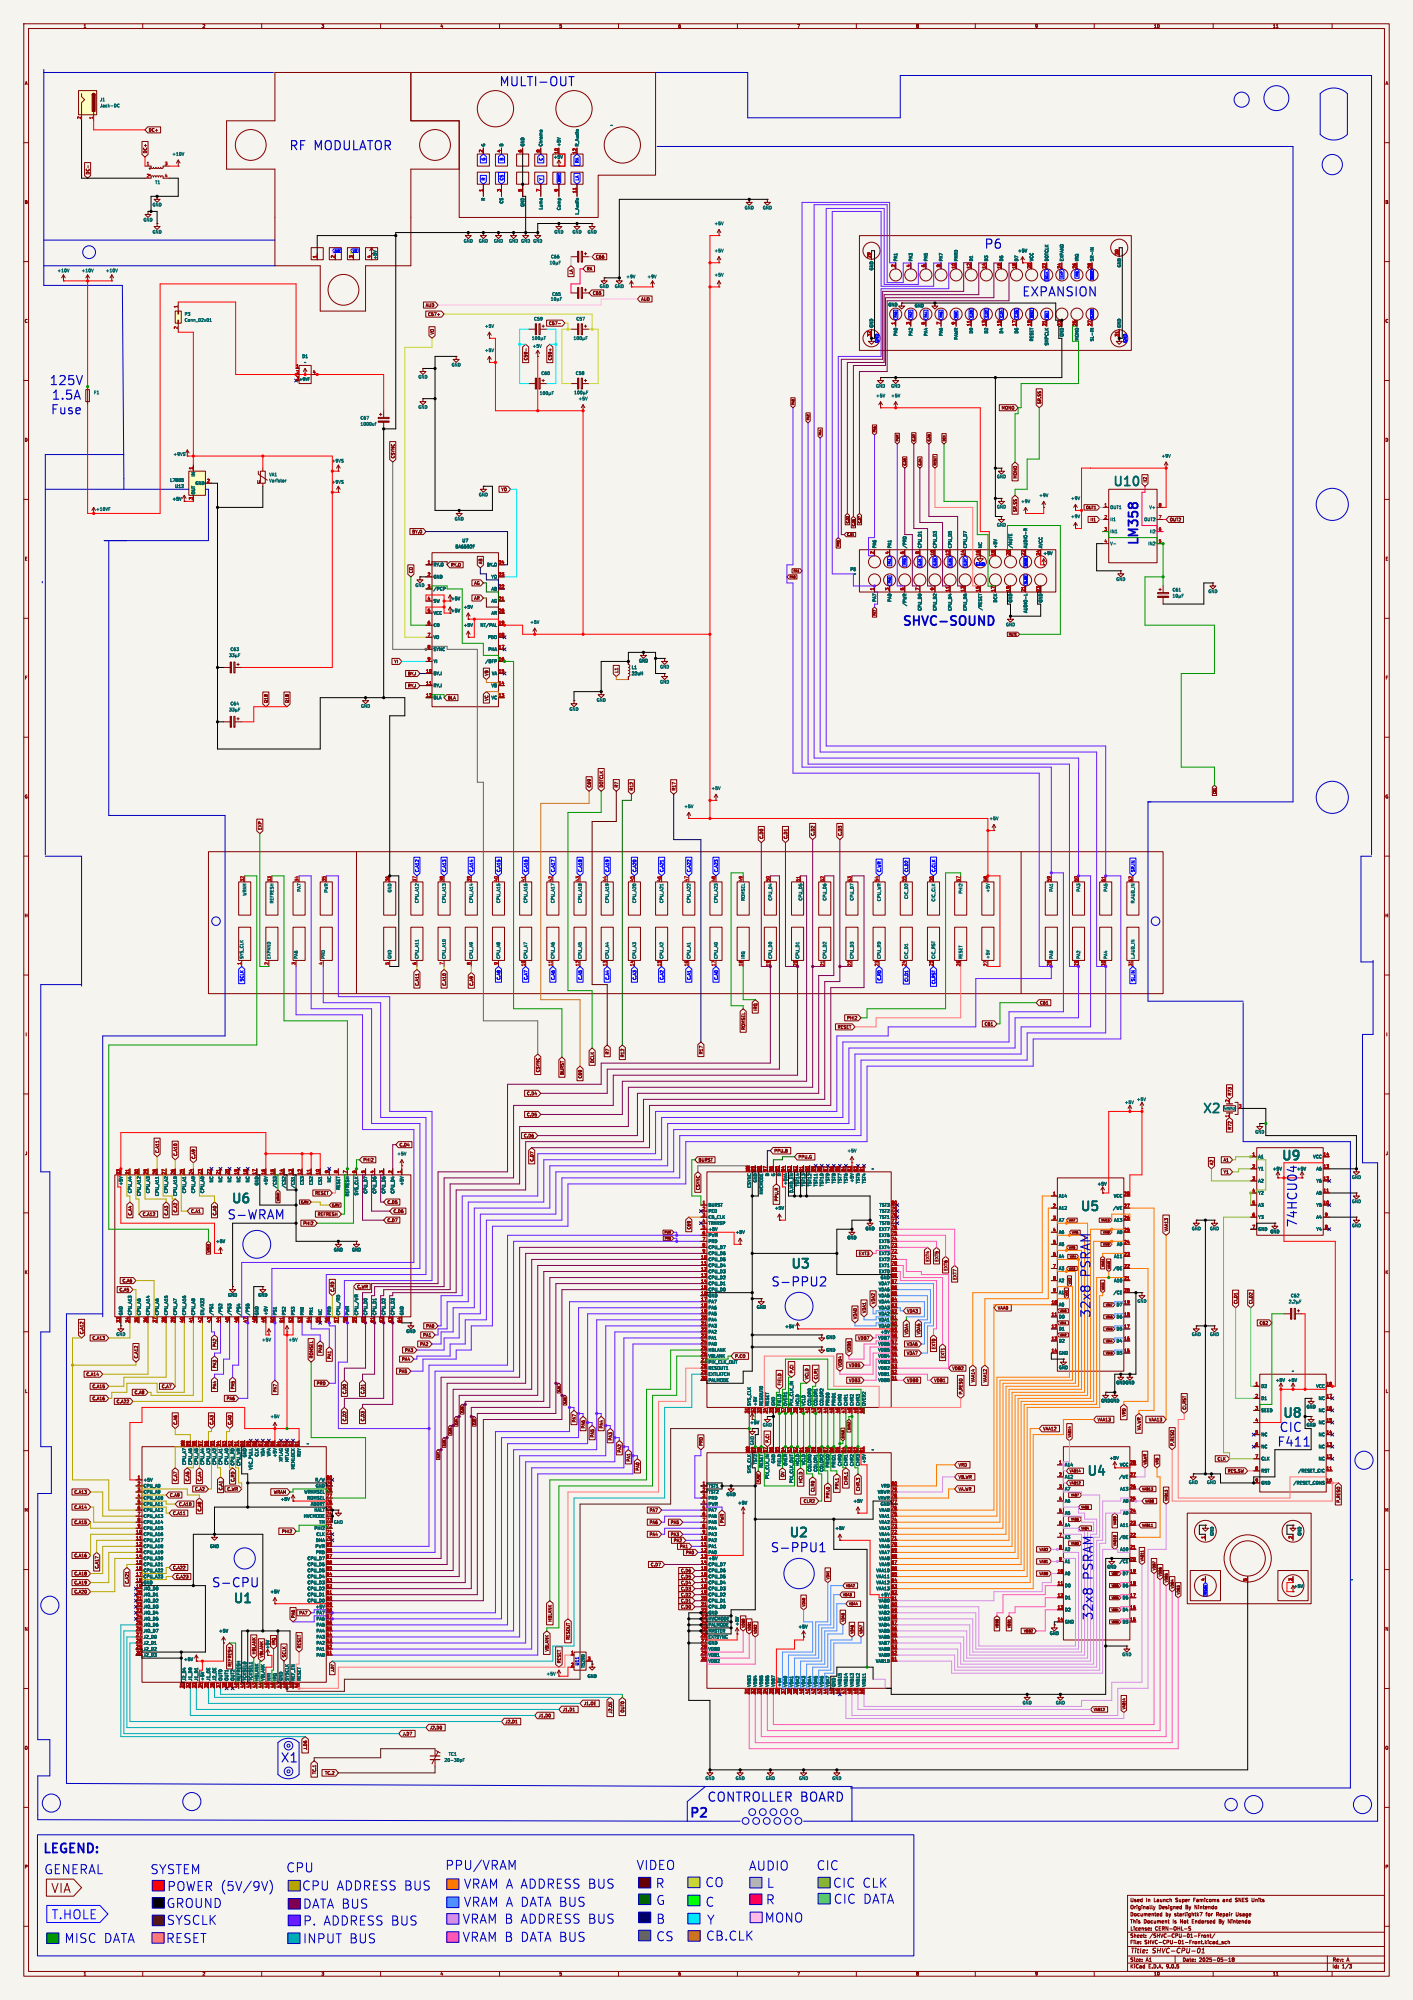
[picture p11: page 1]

Y PA6 CI.D2 IRQ C.WR REFRESH VBLANK HBLANK COMP LA C.CLK C.D2 C.D3 CI.RST

9 D1 12 D0 11 D3 14 D2 13 D5 16 D4 15 D7 18 D6 17 VCC 20 RESET 19 DOTCLK 22 SMPCLK 21 EXPAND 24 GND 23 IRQ 26 MONO 25 SR-IN 28 SL-IN 27 GND 30 GND 31 GND

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

9 CPU_D5 12 CPU_D4 11 CPU_D7 14 CPU_D6 13 NC 16 /RESET 15 +5V 18 DCK 17 /MUTE 20 GND 19 AUDIO-R 22 AUDIO-L 21 AVCC 24 GND 23 P5~

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

9 NC 55 CS1 10 PA1 54 CS2 11 PA0 53 CS3 12 PS3 52 /CS1 13 PS2 51 /CS2 14 PS1 50 /CS3 15 +5V 49 +5V 16 GND 48 GND 17 /PS5 47 NC 18 /PS4 46 NC 19 /PS3 45 NC 20 /PS2 44 NC 21 /PS1 43 NC 22 EN/A22 42 CPU_A0 23 CPU_A8 41 CPU_A9 24 CPU_A16 40 CPU_A1 25 CPU_A7 39 CPU_A10 26 CPU_A15 38 CPU_A2 27 CPU_A6 37 CPU_A11 28 CPU_A14 36 CPU_A3 29 CPU_A5 35 CPU_A12 30 CPU_A13 34 CPU_A4 31 GND 33 +5V 32

File: SHVC-CPU-01-Front.kicad_sch Sheet: /SHVC-CPU-01-Front/ License: CERN-OHL-S

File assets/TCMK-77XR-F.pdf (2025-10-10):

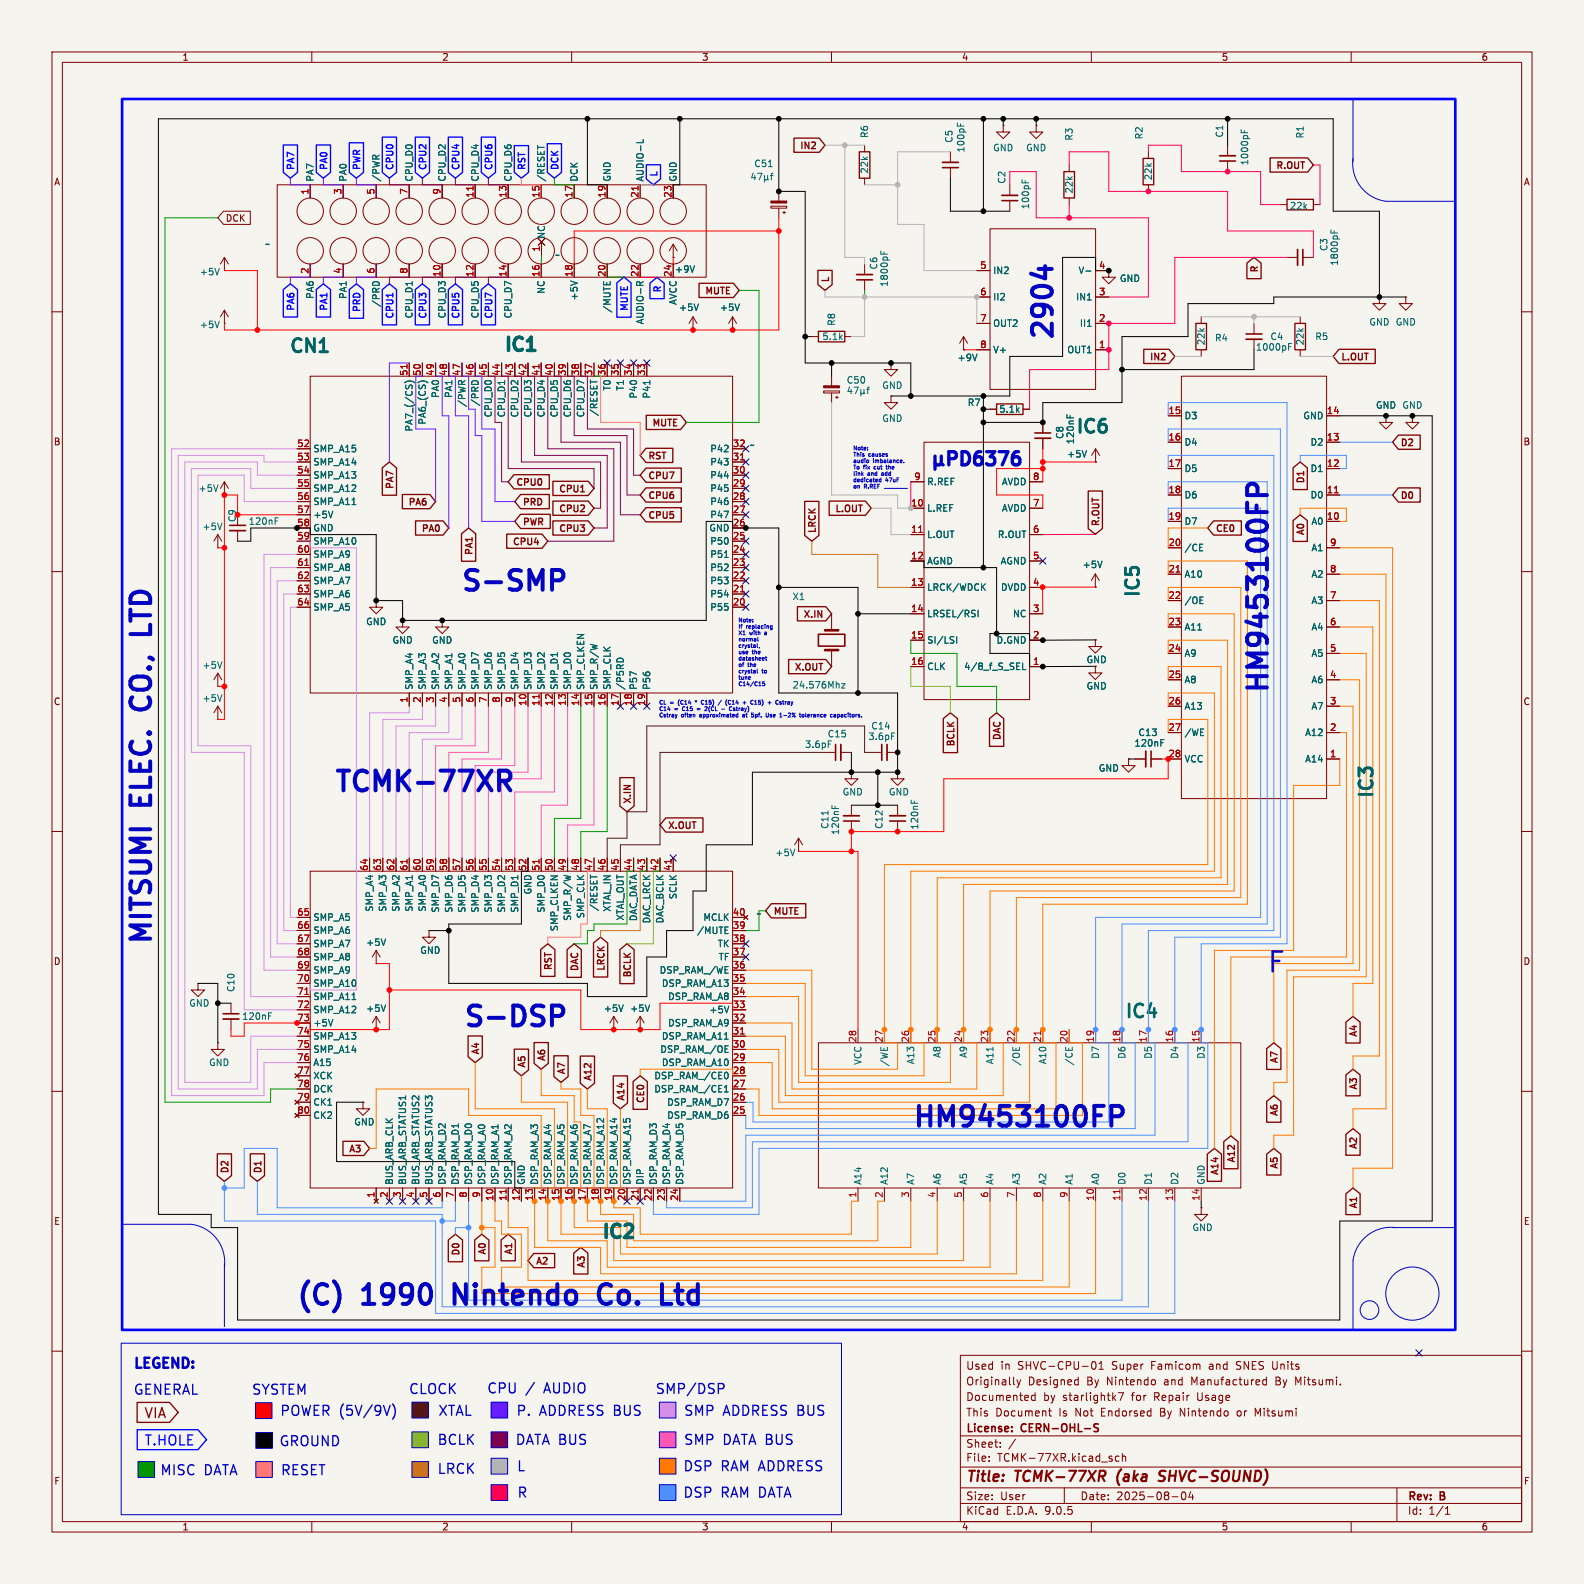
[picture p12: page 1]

9 CPU_D3 10 CPU_D4 11 CPU_D5 12 CPU_D6 13 CPU_D7 14 /RESET 15 NC 16 DCK 17 +5V 18 GND 19 /MUTE 20 AUDIO-L 21 AUDIO-R 22 GND 23 AVCC 24

Note: This causes audio imbalance. To fix cut the

tune C14/C15 RESET MITSUMI ELEC. CO., LTD

normal crystal, use the

9 SMP_D3 55 DSP_RAM_A1 10 SMP_D2 54 DSP_RAM_A2 11 SMP_D1 53 GND 12 GND 52 DSP_RAM_A3 13 SMP_D0 51 DSP_RAM_A4 14 SMP_CLKEN 50 DSP_RAM_A5 15 SMP_R/W 49 DSP_RAM_A6 16 SMP_CLK 48 DSP_RAM_A7 17 /RESET 47 DSP_RAM_A12 18 XTAL_IN 46 DSP_RAM_A14 19 XTAL_OUT 45 DSP_RAM_A15 20 DAC_DATA44 DIP 21 DAC_LRCK 43 DSP_RAM_D3 22 DAC_BCLK 42 DSP_RAM_D4 23 SCLK 41 DSP_RAM_D5 24 MCLK 40

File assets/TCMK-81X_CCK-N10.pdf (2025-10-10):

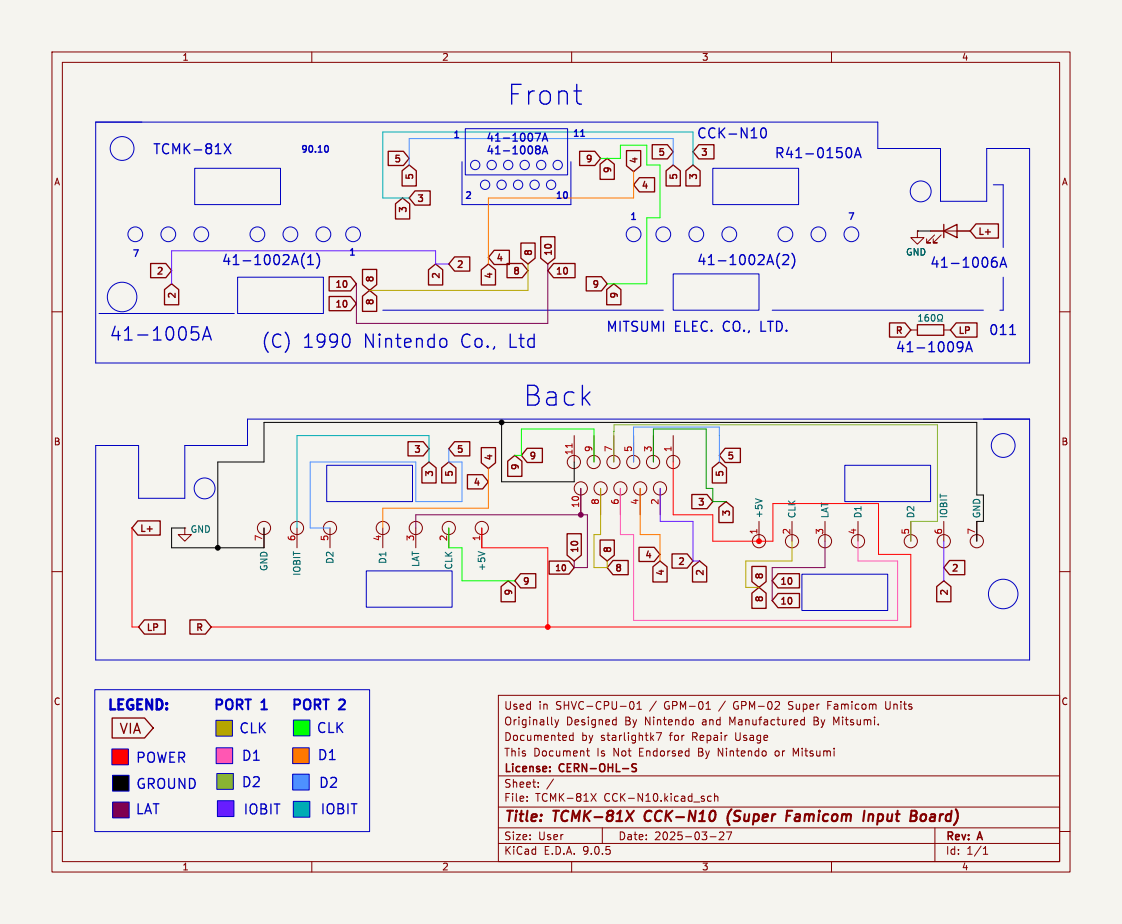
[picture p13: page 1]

MITSUMI ELEC. CO., LTD. 1

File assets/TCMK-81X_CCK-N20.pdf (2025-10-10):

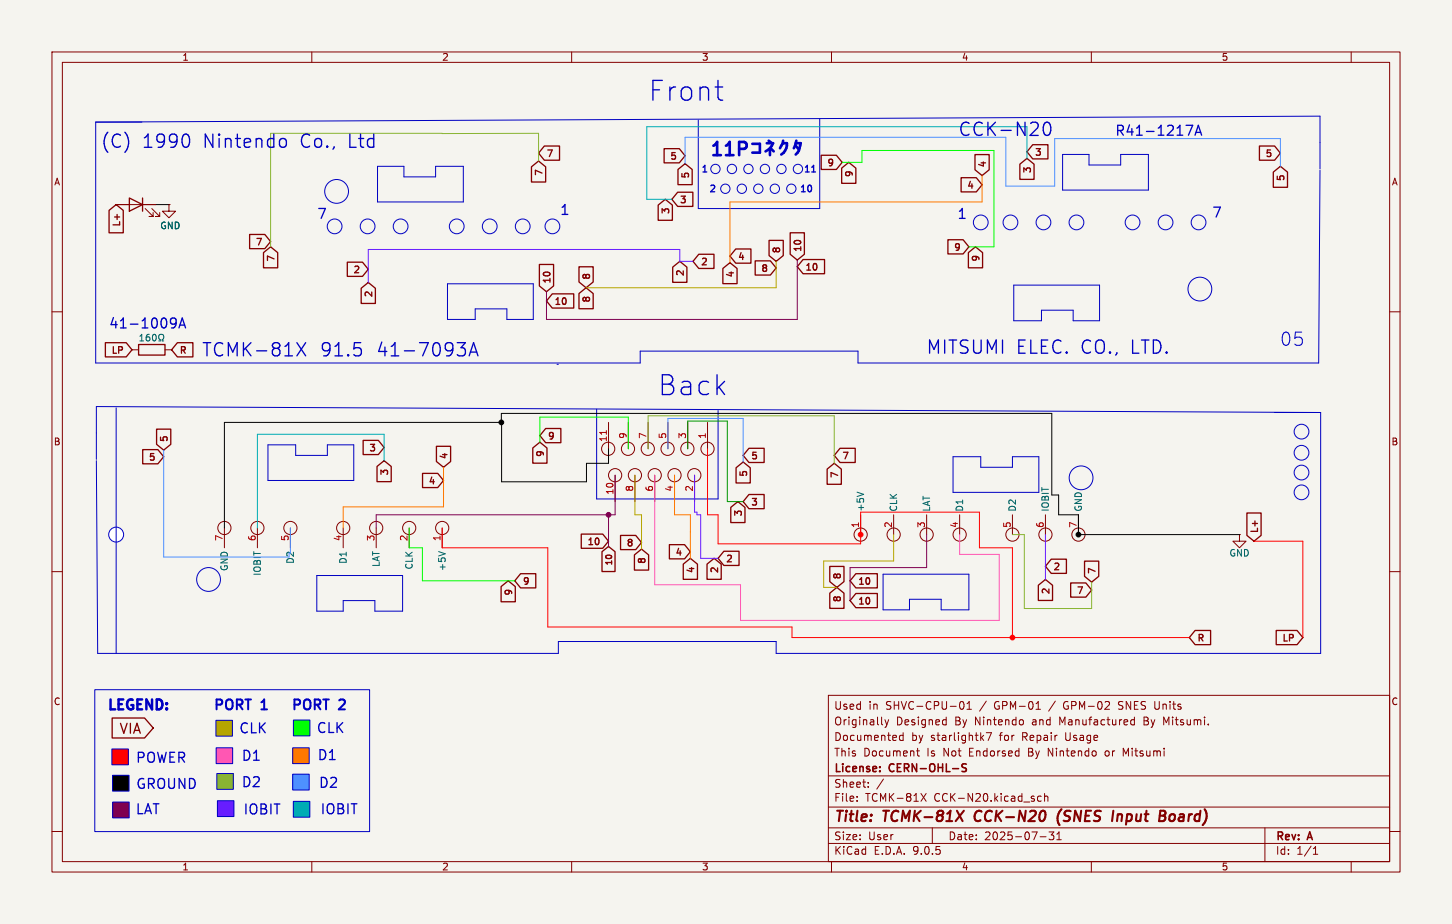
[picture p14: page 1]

CCK-N20 | R41-1217A

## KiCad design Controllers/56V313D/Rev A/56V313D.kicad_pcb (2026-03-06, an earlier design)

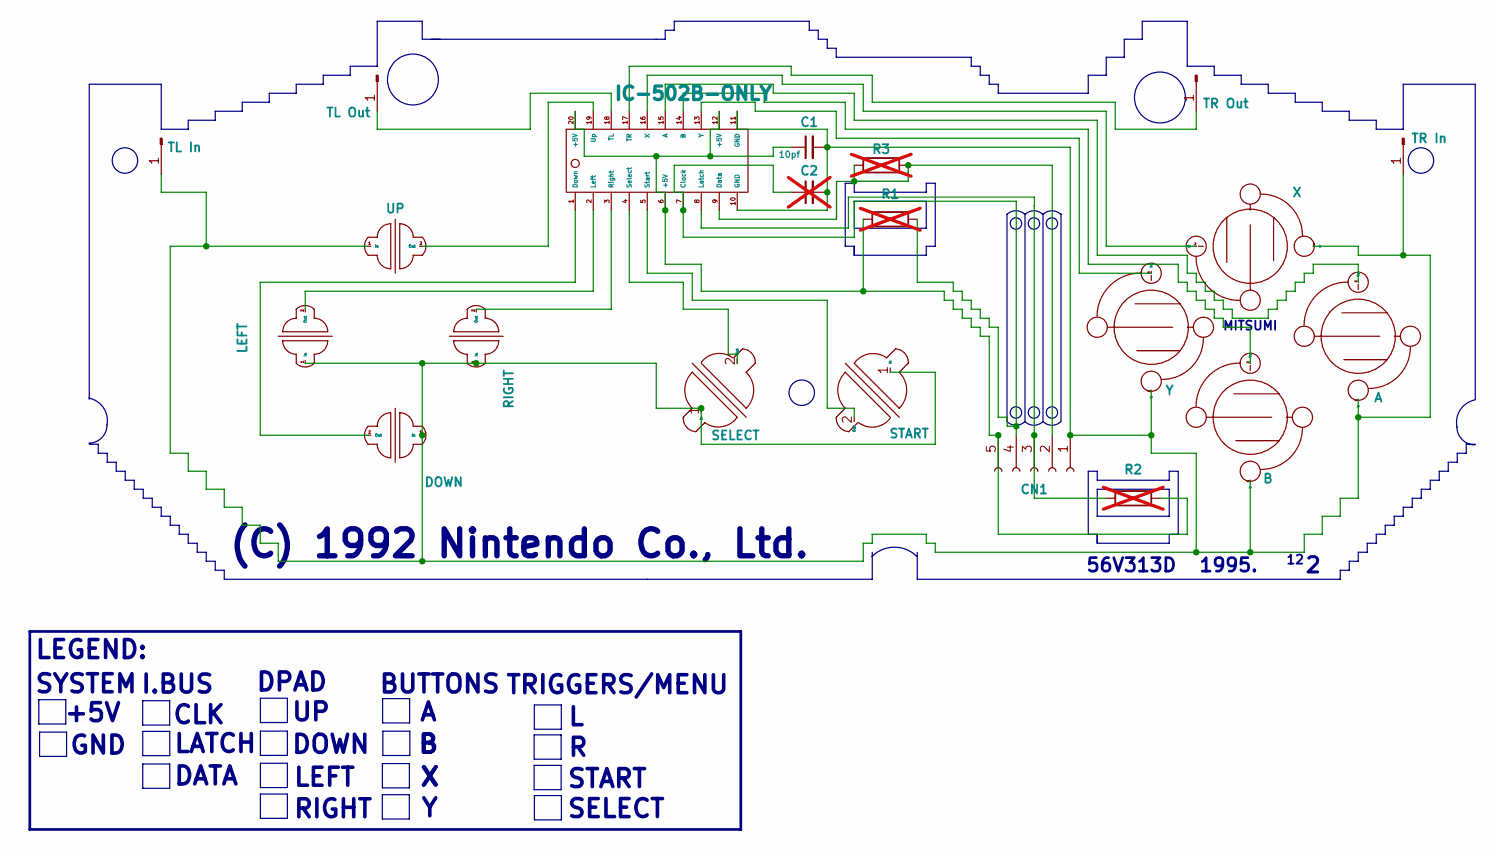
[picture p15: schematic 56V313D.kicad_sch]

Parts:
C1: 10pf; C_0805_2012Metric
C2: C_Small; C_0805_2012Metric; not fitted
CN1: Cord Connector; PinHeader_1x05_P2.00mm_Vertical
IC1: IC-502B-ONLY; IC-520B
J1: TR Out; PinHeader_1x01_P2.54mm_Vertical
J2: TR In; PinHeader_1x01_P2.54mm_Vertical
J3: TL In; PinHeader_1x01_P2.54mm_Vertical
J4: TL Out; PinHeader_1x01_P2.54mm_Vertical
R1, R2, R3: R; R_0805_2012Metric; not fitted
S1: LEFT; DPadShoulderButton
S2: SELECT; StartSelectButton
S3: UP; DPadShoulderButton
S4: RIGHT; DPadShoulderButton
S5: DOWN; DPadShoulderButton
S6: START; StartSelectButton
S7: Y; FaceButton
S8: X; FaceButton
S9: B; FaceButton
S10: A; FaceButton

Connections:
unnamed: C1.2, C2.2, CN1.1, IC1.10 (GND), IC1.11 (GND), J2.1, J3.1, S1.1 (In), S2.1 (In), S3.1 (In), S4.1 (In), S5.1 (In), S6.1 (In), S7.1 (In), S8.1 (In), S9.1 (In), S10.1 (In)
unnamed: CN1.2, IC1.9 (Data), R3.1, R3.2
unnamed: CN1.3, IC1.8 (Latch), R2.1
unnamed: C2.1, CN1.4, IC1.7 (Clock), R1.2
unnamed: C1.1, CN1.5, IC1.6 (+5V), IC1.12 (+5V), IC1.20 (+5V), R1.1, R2.2
unnamed: IC1.15 (A), S10.2 (Out)
unnamed: IC1.14 (B), S9.2 (Out)
unnamed: IC1.1 (Down), S5.2 (Out)
unnamed: IC1.2 (Left), S1.2 (Out)
unnamed: IC1.3 (Right), S4.2 (Out)
unnamed: IC1.4 (Select), S2.2 (Out)
unnamed: IC1.5 (Start), S6.2 (Out)
unnamed: IC1.18 (TL), J4.1
unnamed: IC1.17 (TR), J1.1
unnamed: IC1.19 (Up), S3.2 (Out)
unnamed: IC1.16 (X), S8.2 (Out)
unnamed: IC1.13 (Y), S7.2 (Out)

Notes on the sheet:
GND
RIGHT
+5V
LEFT
DOWN
SYSTEM
LATCH
(C) 1992 Nintendo Co., Ltd.
SELECT
START
TRIGGERS/MENU
MITSUMI
LEGEND:
CLK
56V313D
DATA
1995.
BUTTONS
I.BUS
DPAD

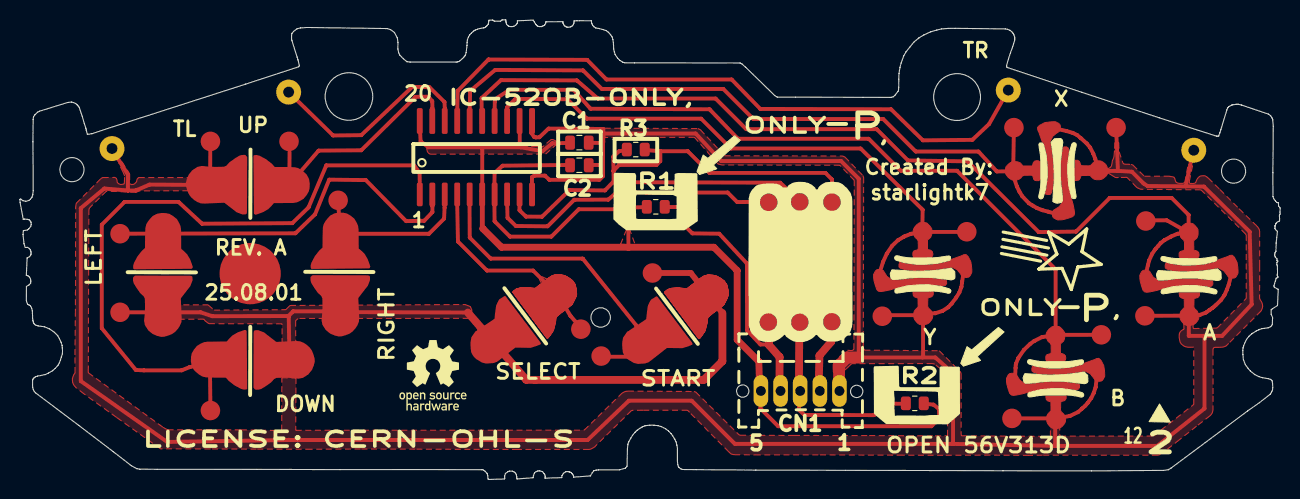
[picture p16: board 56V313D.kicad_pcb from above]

Board: 2 copper layers, 128.3 x 46.8 mm, 21 parts (0 on the bottom side), 17 nets.

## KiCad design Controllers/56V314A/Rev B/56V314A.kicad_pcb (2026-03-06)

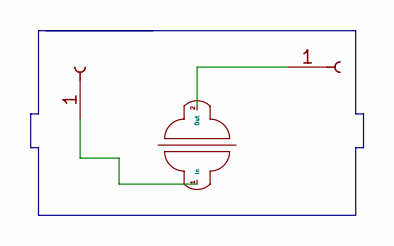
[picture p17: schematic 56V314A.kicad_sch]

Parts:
J1, J2: Conn_01x01_Socket; PinHeader_1x01_P2.54mm_Vertical
S1: DPadShoulderButtonV2

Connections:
unnamed: J1.1, S1.1 (In)
unnamed: J2.1, S1.2 (Out)

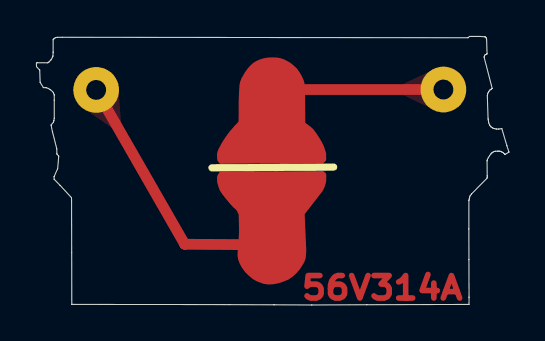
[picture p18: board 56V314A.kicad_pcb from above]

Board: 2 copper layers, 26.3 x 14.9 mm, 3 parts (0 on the bottom side), 2 nets.

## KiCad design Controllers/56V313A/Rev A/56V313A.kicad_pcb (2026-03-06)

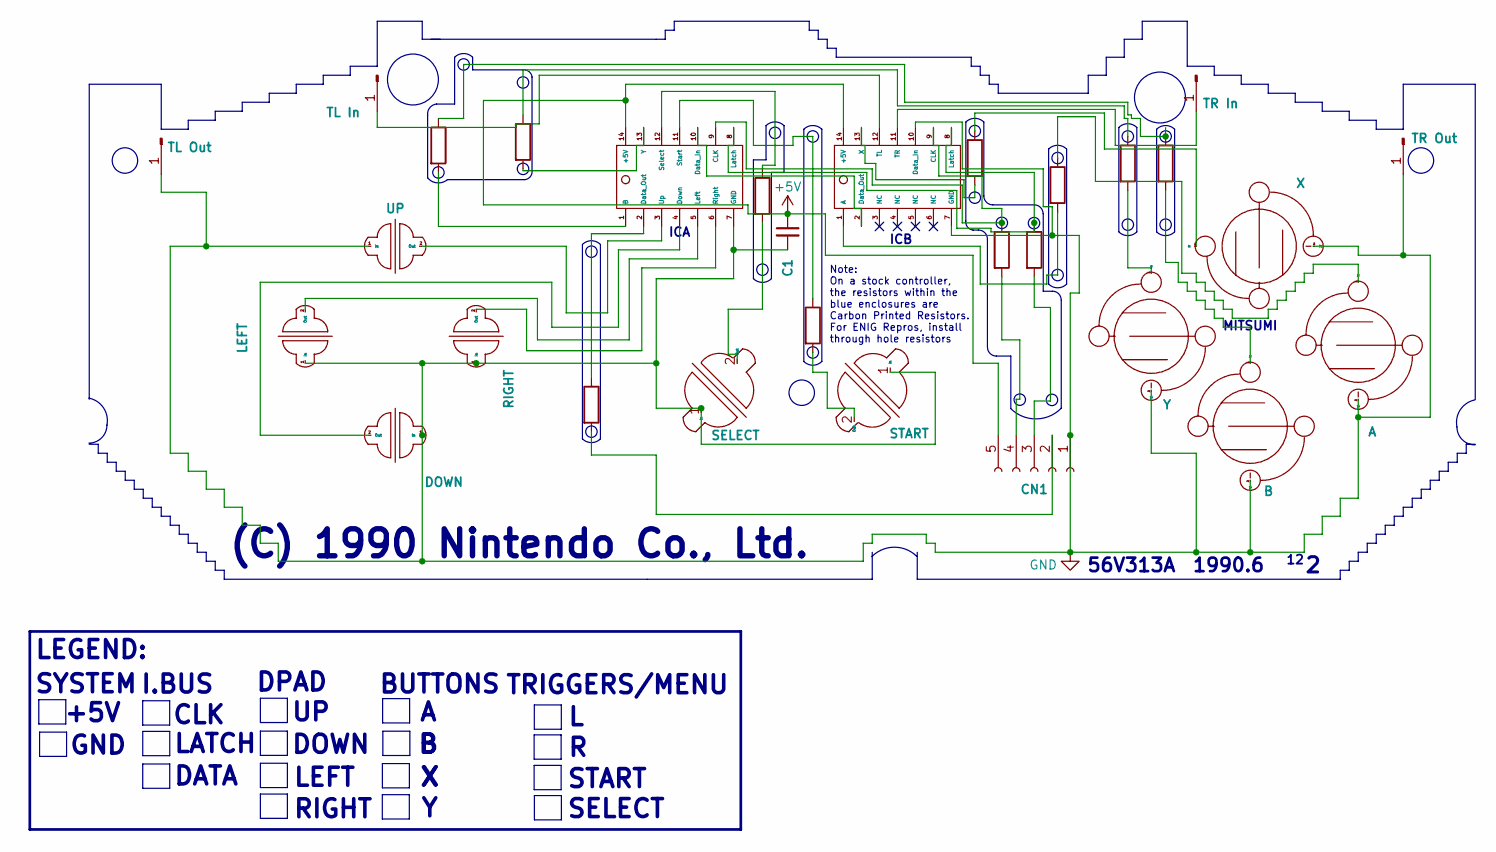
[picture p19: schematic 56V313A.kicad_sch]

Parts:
C1: 10pf; C_0805_2012Metric
CN1: Cord Connector; PinHeader_1x05_P2.00mm_Vertical
IC1, IC2: IC_AB
J1: TR In; PinHeader_1x01_P2.54mm_Vertical
J2: TR Out; PinHeader_1x01_P2.54mm_Vertical
J3: TL Out; PinHeader_1x01_P2.54mm_Vertical
J4: TL In; PinHeader_1x01_P2.54mm_Vertical
R1: R; Controller1990_T11
R2: Controller1990_T2
R3: R; Controller1990_T1
R4: R; Controller1990_T3
R5: R; Controller1990_T4
R6: R
R7: R; Controller1990_T6
R8: R; Controller1990_T7
R9: R; Controller1990_T8
R10: R; Controller1990_T9
R11: R; Controller1990_T10
S1: LEFT; DPadShoulderButton
S2: SELECT; StartSelectButton
S3: UP; DPadShoulderButton
S4: RIGHT; DPadShoulderButton
S5: DOWN; DPadShoulderButton
S6: START; StartSelectButton
S7: Y; FaceButtonV2
S8: X; FaceButtonV2
S9: B; FaceButtonV2
S10: A; FaceButtonV2

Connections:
+5V: C1.1, CN1.5, IC1.14 (+5V), IC2.14 (+5V)
GND: C1.2, CN1.1, IC1.7 (GND), IC2.7 (GND), IC2.10 (Data_In), J2.1, J3.1, S1.1 (In), S2.1 (In), S3.1 (In), S4.1 (In), S5.1 (In), S6.1 (In), S7.2 (Out), S8.2 (Out), S9.2 (Out), S10.2 (Out)
unnamed: CN1.2, R1.2
unnamed: CN1.3, R8.2
unnamed: CN1.4, R7.2
unnamed: IC1.1 (B), R3.2
unnamed: IC1.9 (CLK), IC2.9 (CLK), R7.1
unnamed: IC1.10 (Data_In), IC2.2 (Data_Out)
unnamed: IC1.2 (Data_Out), R1.1
unnamed: IC1.4 (Down), S5.2 (Out)
unnamed: IC1.8 (Latch), IC2.8 (Latch), R8.1
unnamed: IC1.5 (Left), S1.2 (Out)
unnamed: IC1.6 (Right), S4.2 (Out)
unnamed: IC1.12 (Select), R4.1
unnamed: IC1.11 (Start), R5.1
unnamed: IC1.3 (Up), S3.2 (Out)
unnamed: IC1.13 (Y), R2.2
unnamed: IC2.1 (A), R9.2
unnamed: IC2.12 (TL), J4.1
unnamed: IC2.11 (TR), J1.1
unnamed: IC2.13 (X), R6.2
unnamed: R2.1, R10.1
unnamed: R3.1, R11.1
unnamed: R4.2, S2.2 (Out)
unnamed: R5.2, S6.2 (Out)
unnamed: R10.2, S7.1 (In)
unnamed: R6.1, S8.1 (In)
unnamed: R11.2, S9.1 (In)
unnamed: R9.1, S10.1 (In)

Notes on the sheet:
GND
RIGHT
+5V
LEFT
ICA
DOWN
Note: On a stock controller, the resistors within the blue enclosures are Carbon Printed Resistors. For ENIG Repros, install through hole resistors
SYSTEM
LATCH
ICB
(C) 1990 Nintendo Co., Ltd.
SELECT
START
TRIGGERS/MENU
MITSUMI
LEGEND:
CLK
56V313A
DATA
1990.6
BUTTONS
I.BUS
DPAD

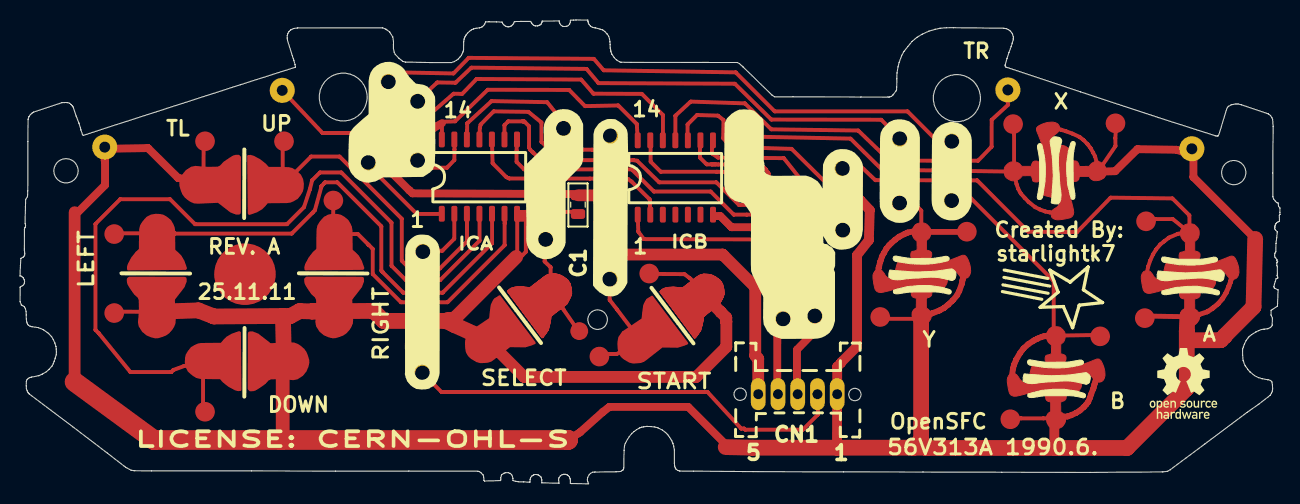
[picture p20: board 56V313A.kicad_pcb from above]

Board: 2 copper layers, 127.6 x 47.0 mm, 29 parts (0 on the bottom side), 29 nets.

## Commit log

2025-10-10 Initial Relase of Documentation
    [OSFC-BOM.ods]
2025-10-27 Migrate BOM to Google Docs, Fix C82
    For some reason C82 was no on the spreadsheet even though its on
    the iBOM and Schematic. I fixed that (12nF) and also migrated the
    bom to Google Docs for easier accessibility and maintenance.
    [OSFC-BOM.ods]
2025-10-27 Release SHVC-CPU-01 Rev A SP1 Back Schematic
    Fixes transistor symbols which were visually inaccurate, though
    wired correctly.
    Thanks to RGBeter for reporting this issue.
2025-10-30 Release SHVC-CPU-01 Rev A SP2 Back Schematic
    Also corrects visual inaccuracy in the audio transistors.
2026-03-06 Release OpenSFC Controllers: 1990 and 1992 Models
    Initial release.
    [56V313A.kicad_pcb, 56V313A.kicad_sch, 56V313D.kicad_pcb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]
2026-03-24 Fix schema note for Audio Balance Mod
    Noted the wrong pin to attach the cap to on the schematic diagram
    comments.
    I apologize for the mistake and thanks to /u/Yekomhxc for reporting
    There was no mistake on the actual board itself.
    [TCMK-77XR.kicad_sch]
